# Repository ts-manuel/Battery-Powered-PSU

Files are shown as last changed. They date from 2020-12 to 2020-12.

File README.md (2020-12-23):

# Battery Powered PSU
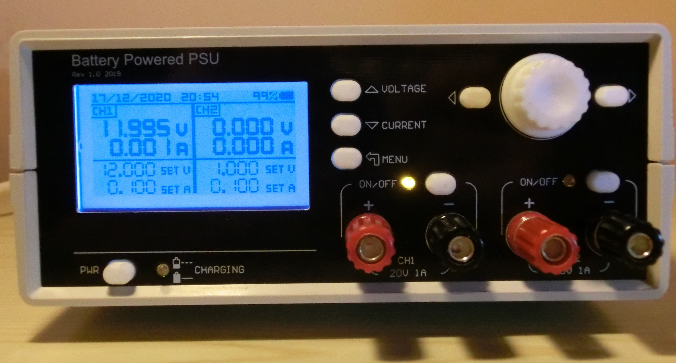
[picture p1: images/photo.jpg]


<!-- TABLE OF CONTENTS -->
<details open="open">
  <summary>Table of Contents</summary>
  <ol>
    <li>
      <a href="#about-the-project">About The Project</a>
    </li>
    <li>
      <a href="#getting-started">Getting Started</a>
      <ul>
        <li><a href="#prerequisites">Prerequisites</a></li>
      </ul>
    </li>
    <li>
        <a href="#theory-of-operation">Theory of Operation</a>
        <ul>
            <li><a href="#battery-block-diagram">Battery Block Diagram</a></li>
            <li><a href="#soc-estimation">SOC Estimation</a></li>
            <li><a href="#charging-and-balancing">Charging and Balancing</a></li>
            <li><a href="#psu-block-diagram">PSU Block Diagram</a></li>
            <li><a href="#custom-transformers">Custom Transformers</a></li>
        </ul>
    </li>
    <li><a href="#future-improvements">Future Improvements</a></li>
    <li><a href="#references">References</a></li>
    <li><a href="#disclaimer">Disclaimer</a></li>
  </ol>
</details>

<!-- ABOUT THE PROJECT -->
## About The Project
This is a dual-channel power supply powered by 6 18650 Lithium-Ion cells. If like me you don't have lots of space, having a power supply that you can move and get out of the way without getting tangled in cables is quite useful. Inspiration comes from the [uSupply](https://www.eevblog.com/projects/usupply/) designed by Dave Jones on the EEVblog. The only thing this has in common with the original uSupply is the [LT3080](https://www.analog.com/media/en/technical-documentation/data-sheets/3080fc.pdf) low dropout voltage regulator on the output. The remaining hardware has been completely engineered from scratch.\
Schematics and PCBs are designed with Circuit Maker, [link](https://workspace.circuitmaker.com/Projects/Details/ts-manuel/Battery-Powered-PSU-Final) to the project.
### Specifications:
* Powered from 6 x 18650 Lithium-Ion cells (56Wh)
* 2x 20V 1A Isolated outputs
* 1 mV Voltage resolution
* 1 mA Current resolution

<!-- GETTING STARTED -->
## Getting Started
There are two MPLAB X projects, `software\BatteryController.X`  is for the battery microcontroller and `software\PowerSupply.X` is for the main power supply microcontroller. To compile the code just open them into MPLAB X.
### Prerequisites
* [MPLAB X v5.30](https://www.microchip.com/development-tools/pic-and-dspic-downloads-archive)
* [MPLAB Code Configurator v4.x](https://www.microchip.com/mplab/mplab-code-configurator)

<!-- BLOCK DIAGRAM -->
## Theory of Operation
The project is split into two circuit boards. The one on the left is the battery, the other is the power supply. The battery board holds six Lithium-Ion cells, the protection and charger circuitry, and a microcontroller to keep track of the SOC (State Of Charge). All the components besides the cells are located on the backside. The power supply board on the right has all the circuitry to handle the user interface and to generate the output voltages. The output voltage is regulated in two steps, there's a switching pre-regulator to keep efficiency high followed by a linear one to reduce noise.
The two boards are connected by a 10-way cable that carries power and control signals. When the power supply is on, the battery sends its SOC to the PSU via UART.
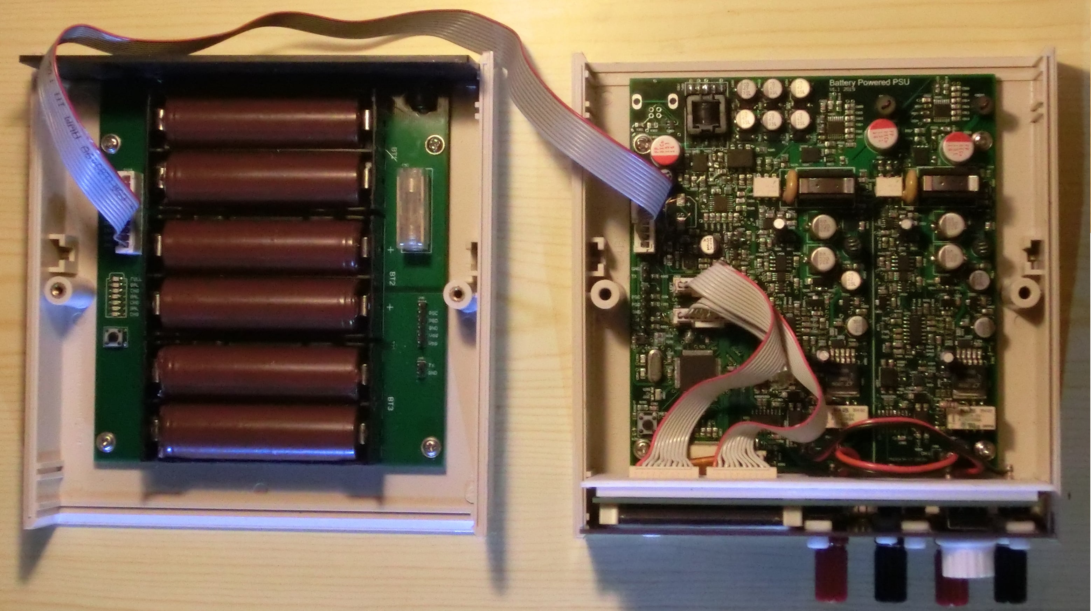
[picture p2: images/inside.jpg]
Inside


### Battery Block Diagram
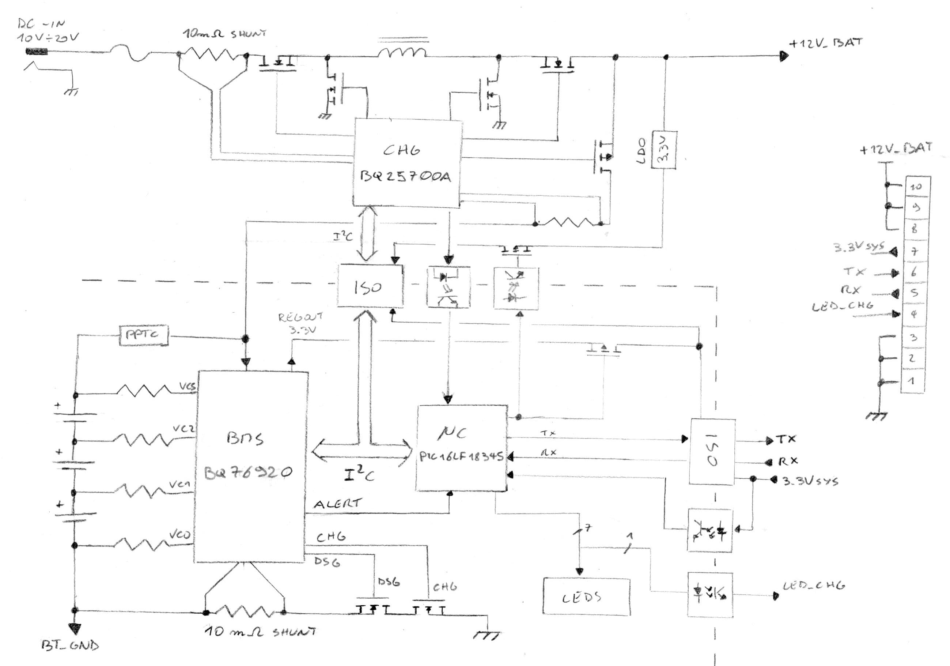
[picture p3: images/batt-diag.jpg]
Battery Block Diagram
\
This is the simplified block diagram for the battery board. This board is responsible for charging and protecting the Lithium-Ion cells. The three main components are the BMS IC, the charging IC, and the microcontroller.\
The BMS [BQ76920](https://www.ti.com/lit/ds/symlink/bq76940.pdf?ts=1608322350104&ref_url=https%253A%252F%252Fwww.google.com%252F) from Texas Instruments, continuously monitors cell voltages and current. If an over-voltage, under-voltage, or over-current condition is detected the cells are immediately disconnected. The IC also features internal balancing FETs that are activated by the microcontroller to balance the cells. The BMS is connected to the microcontroller through I2C.\
The Charger IC [BQ25700A](https://www.ti.com/lit/ds/symlink/bq25700a.pdf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) also from Texas Instruments uses a switching buck-boost converter to take the input voltage and charge the cells with a constant-current constant-voltage scheme. Its I2C interface is connected to the microcontroller through an I2C isolator.\
The microcontroller is a [PIC16LF18345](http://ww1.microchip.com/downloads/en/devicedoc/40001795e.pdf) from Microchip. It keeps track of the battery SOC, balances the cels, and enables/disables the charger. The microcontroller is connected directly to the batteries, when the BMS goes into protection mode and the cells are disconnected from the rest of the circuit, the only things powered are the BMS and the microcontroller.\
To save power, voltage to the I2C isolators is removed when they're not in use.

### SOC Estimation
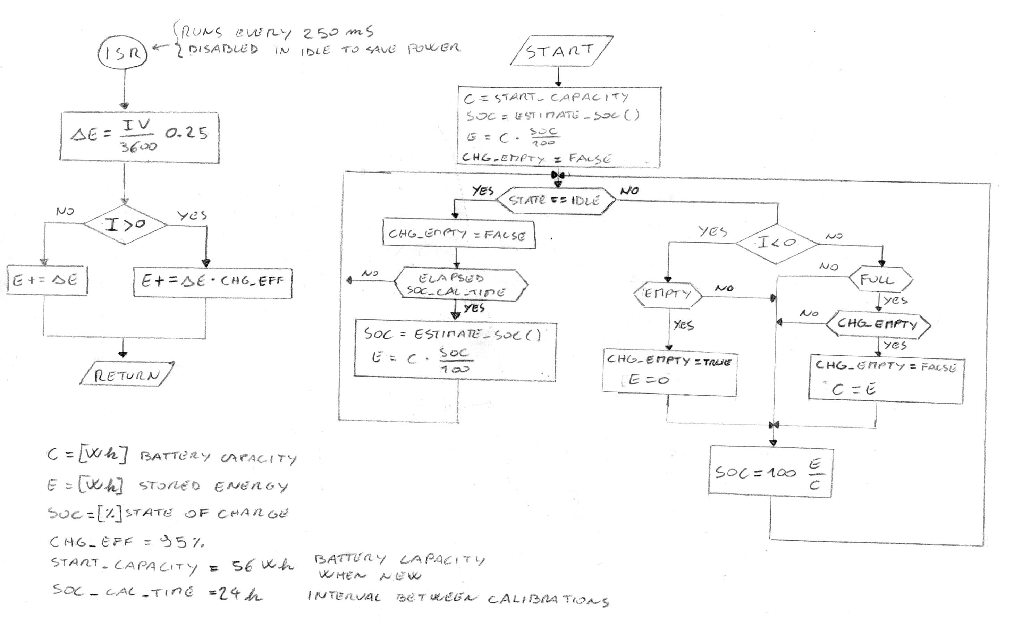
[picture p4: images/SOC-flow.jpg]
SOC Estimation Flow Chart
\
The flow chart above describes the SOC Estimation algorithm adopted, it is a variation of this [Coulomb-Counting Algorithm](https://arxiv.org/ftp/arxiv/papers/1803/1803.10654.pdf). Coulomb-Counting consists of temporal integration of the battery current during charge and discharge. To take into account the battery self-discharge, the SOC is recalibrated by looking at the open-circuit voltage after the battery is left sitting unused for 24 hours. During charge and discharge the coulomb-counter 16-bit ADC inside the BMS is active and configured to trigger an interrupt every 250 ms. Inside the microcontroller, there are three variables: capacity, energy, and SOC. When the board is first powered the capacity is initialized with the expected capacity from a new set of cells, the SOC is estimated from the open-circuit voltage, and energy is set as a fraction of the initial capacity based upon the SOC. Each time the BMS triggers an interrupt the energy is updated, when the battery is empty the energy is set to zero.
At the end of the charging process, if the battery has been charged from empty without interruptions, the accumulated energy is by definition the real battery capacity so the capacity variable is updated. This takes into account the aging of the cells in the SOC estimations.

### Charging and Balancing
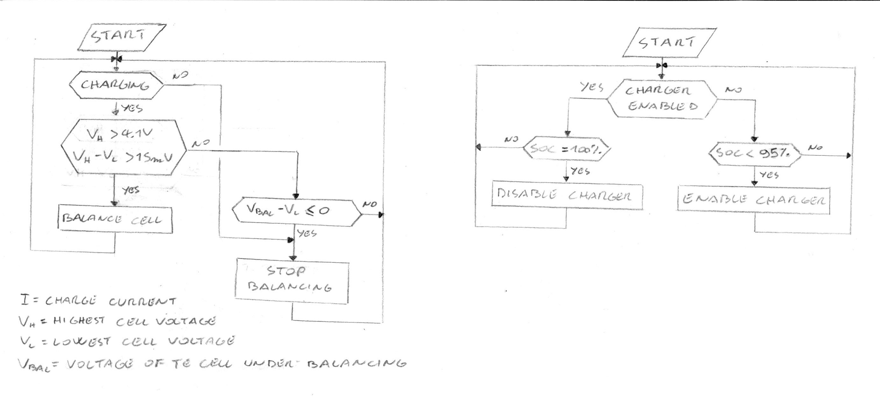
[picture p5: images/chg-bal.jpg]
Charging-Balancing Flowchart
\
The microcontroller controls the charger IC, when the charging cable is plugged in, the charger is enabled if the SOC is less than 95% and it's disabled when SOC reaches 100%.\
Balancing is performed only near the end of charge when the cell voltages are closer. If the difference in voltage between cells is greater than 15 mV, the balancing FET for the cell with the highest voltage is activated. It remains active until its voltage equals that of another cell. This simple scheme works surprisingly well. Once the cells are balanced they remain aligned pretty much on their own and only small corrections are needed.

### PSU Block Diagram
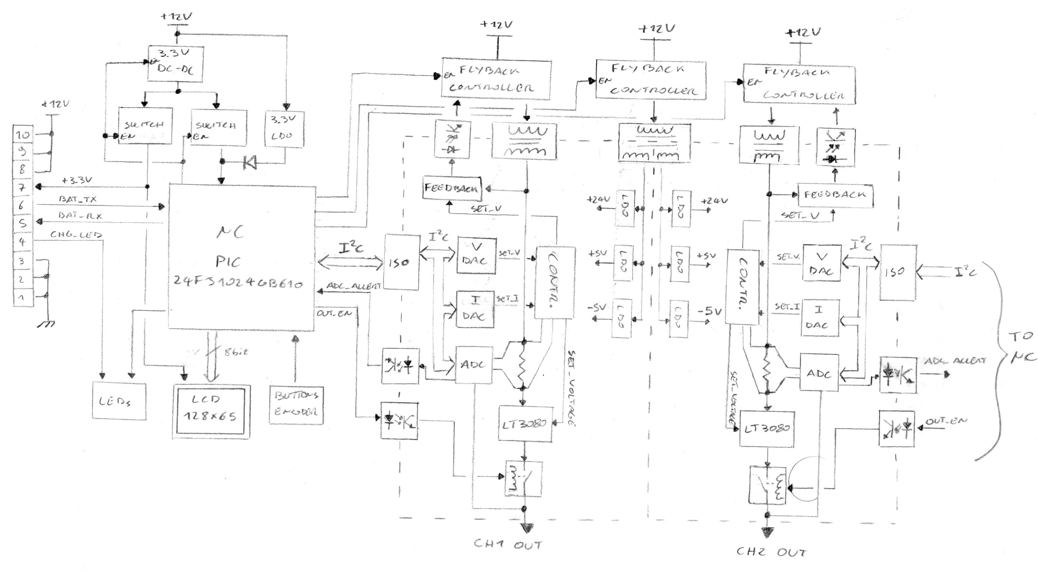
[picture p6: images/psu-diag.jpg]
PSU Block Diagram
\
This is the block diagram for the power supply. The microcontroller [PIC24FJ1024GB610](https://www.microchip.com/wwwproducts/en/PIC24FJ1024GB610) handles the user interface and controls the rest of the circuitry. The connection to the LCD uses the EPMP peripheral configured as an 8-bit 6800 bus. The buttons and the encoder are handled by interrupts. When the power supply is turned off, all the flyback converters are disabled, the 3.3V rail is disabled, and the microcontroller enters sleep mode. During sleep the main 8MHz external clock is halted, the only way to wake the CPU is the interrupt triggered by the power button.\
The power supply has two identical isolated channels, to set the output voltage and current limits, each channel has two DACs connected to the same I2C bus through isolators. Control signals are passed on with optocouplers. The output voltage is regulated in two steps, there is a flyback switching converter to keep isolation between channels followed by a linear regulator to reduce noise. The 100KHz clocks for the flyback converters are provided by the microcontroller, the clock signals for the two converters are 180° out of phase, this prevents the primary side MOSFETs from turning on at the same time thus reducing the RMS load on the primary capacitors. There is also a third flyback converter to provide power to the control circuitry.

### Custom Transformers
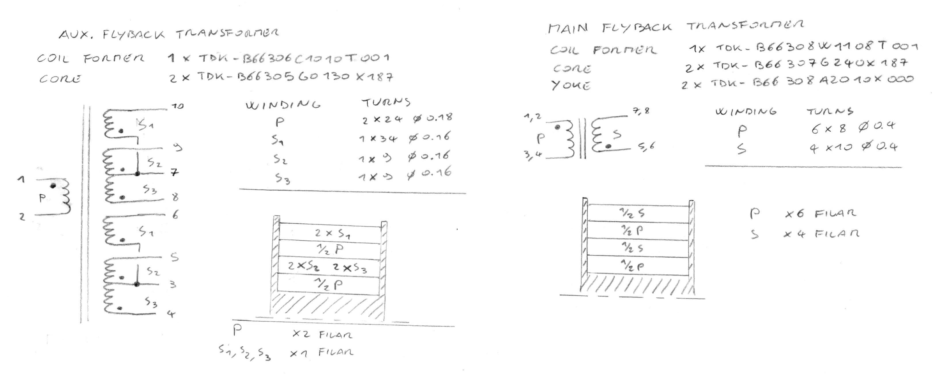
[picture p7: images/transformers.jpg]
Transforrmers
\
There are three custom transformers: two identical ones for the two main flyback converters and one for the auxiliary flyback converter. The picture above shows the winding scheme for each transformer.

<!-- FUTURE IMPROVEMENTS -->
## Future Improvements
* Fix issues with PCBs
* BOM consolidation
* Add USB functionality to the main uC

<!-- REFERENCES -->
## References
* [Implementation of an Improved Coulomb-Counting Algorithm](https://arxiv.org/ftp/arxiv/papers/1803/1803.10654.pdf)
* [A Closer Look at State of Charge and State of Health Estimation Techniques](https://www.analog.com/media/en/technical-documentation/technical-articles/a-closer-look-at-state-of-charge-and-state-health-estimation-techniques.pdf)
* [Lithium-Ion Battery Cell-Balancing Algorithm for Battery Management System Based on Real-Time Outlier Detection](http://downloads.hindawi.com/journals/mpe/2015/168529.pdf)
* [Flyback transformer design considerations for efficiency and EMI](https://www.ti.com/seclit/ml/slup338/slup338.pdf)
* [Flyback Converter Snubber Design](http://www.ridleyengineering.com/images/phocadownload/12_%20flyback_snubber_design.pdf)
* [Battery university - Charging Lithium-ion](https://batteryuniversity.com/learn/article/charging_lithium_ion_batteries)
* [Battery Cell Balancing - What to Balance and How](https://www.ti.com/download/trng/docs/seminar/Topic%202%20-%20Battery%20Cell%20Balancing%20-%20What%20to%20Balance%20and%20How.pdf)
* [Fast Cell Balancing Using External MOSFET](https://www.ti.com/lit/an/slua420a/slua420a.pdf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)
* [Cell balancing buys extra run time and battery life](https://e2echina.ti.com/cfs-file/__key/telligent-evolution-components-attachments/13-112-00-00-00-00-58-11/Cell-balancing-buys-extra-run-time-and-battery-life.pdf)

<!-- DISCLAIMER -->
## Disclaimer
The following project is shared "as is", with the sole objective of being useful. The creator of the described piece of hardware and its associated software cannot guarantee its correct functioning under any circumstance. The author of this project will not be held responsible for any material, personal or economic losses to you or any third parties that may arise from using this design. This project will not be used under any circumstances on systems whose responsibility is critical, or from which people's lives depend upon, directly or indirectly.

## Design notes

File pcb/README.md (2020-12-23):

## Issues with the PCBs
The current PCBs have a couple of issues, to get them working perform the following steps.

### Battery
* Add 10K pull-up resistor to the uC reset pin
* Add 470K pull-up resistor to U50 pin 4
* Cut trace from U101 pin 1 to U100 pin 10 and jumper from U101 pin 1 to U100 pin 1
* Cut trace from connector J101 pin 7, install a series 15 Ohm resistor with a 5V zener diode to GND

### Front Panel Graphics
* No issues

### Front Panel
* No issues

### Power Supply
* Cut trace from resistor R207 and uC
* Cut trace from resistor R208 and uC
* Add jumper from uC pin 43 to R207
* Add jumper across D201
* swap I2C lines for U402 and U404
* Cut trace from U404 pin 1 and connect pull-up resistor to 5V
* Cut trace from U407 pin 2, leave pin 2 floating
* Remove C451, C452 and replace them with a 22uF electrolytic
* Remove C551, C552 and replace them with a 22uF electrolytic
* Put a 4.7uF electrolytic in parallel with R623
* Put a 4.7uF electrolytic in parallel with R523
* Change R520, R620, R670 to 22K

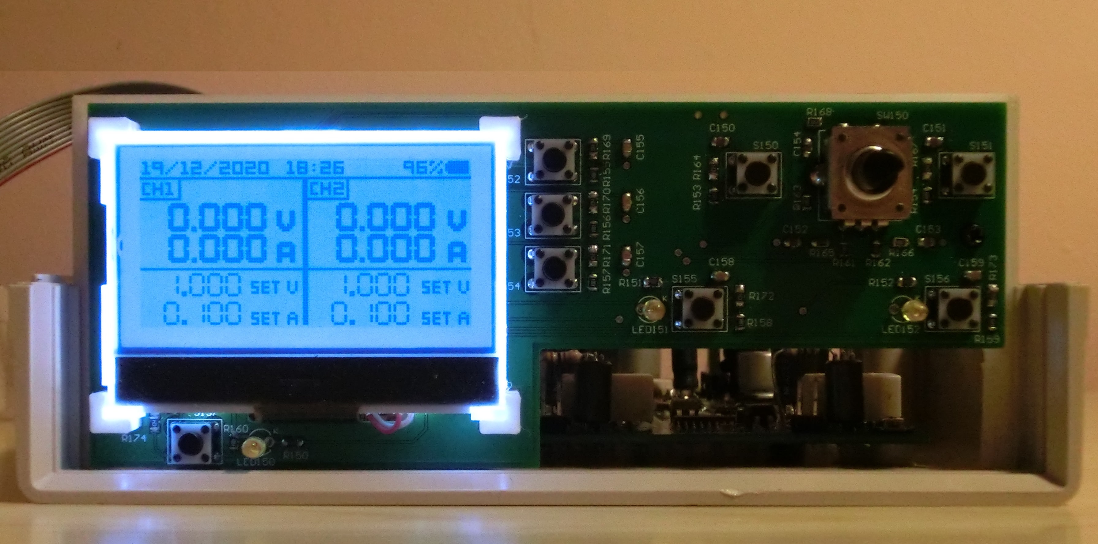
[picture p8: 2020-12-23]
images/front.jpg

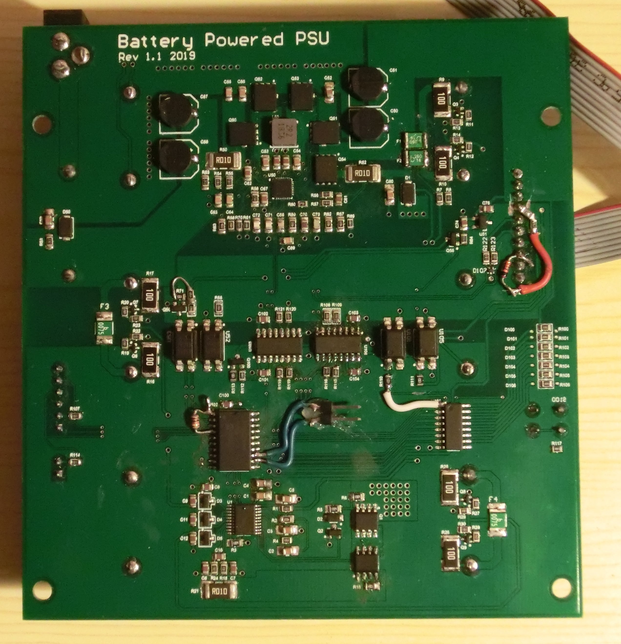
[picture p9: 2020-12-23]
images/battery.jpg

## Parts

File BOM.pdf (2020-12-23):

Quantity | Part Number | Description | Designator | Value
1 | 63074-510-039 CM6-225 Bone Kit (https://www.mouser.it/ProductDetail/PacTec/63074-510-039-CM6-225-Bone-Kit/?qs=e%252B5Je2AHyOjkqM0dwzHt2g%3D%3D) | Enclosures, Boxes & Cases KIT 6.08X6.25X2.5
1 | 3365/10-CUT-LENGTH (https://www.mouser.it/ProductDetail/3M-Electronic-Solutions-Division/3365-10-CUT-LENGTH/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) | Flat Cables .050 10 COND. 28AWG ROUND 1PC=1FT
3 | BK-18650-PC4 | Batt Holder 18650 2 Cell Pc Pin | BT1, BT2, BT3
1 | NHD-C12865AR-FSW-GBW (https://www.mouser.it/ProductDetail/Newhaven-Display/NHD-C12865AR-FSW-GBW/?qs=g3KGrJtCh1xpa8RpWyJ02g%3D%3D) | LCD Graphic Display Modules & Accessories STN-GRAY 59.0 x 42.0 x 5.9 | | 128x65
2 | TX2SA-5V (https://www.mouser.it/ProductDetail/Panasonic-Industrial-Devices/TX2SA-5V/?qs=HLLy2pIPwusM7KldQLtGKQ%3D%3D) | Low Signal Relays - PCB 2A 5VDC DPDT NON-LATCHING SMD | K450, K550
10 | FSM4JH (https://www.mouser.it/ProductDetail/TE-Connectivity-Alcoswitch/FSM4JH/?qs=g%252BEszo6zu8OwVWrHD2r3Rw%3D%3D) | Tactile Switches SPST OFF-(ON) Round pushbutton | S100, S150, S151, S152, S153, S154, S155, S156, S157, S250
1 | EN12-HS22AF20 (https://www.mouser.it/ProductDetail/BI-Technologies-TT-Electronics/EN12-HS22AF20/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) | Encoders 12mm | SW150
1 | LFXTAL003156Bulk (https://www.mouser.it/ProductDetail/IQD/LFXTAL003156Bulk/?qs=e4%2FAndAAwgJ2Z9T5UFLWLw%3D%3D) | Crystals 8.0MHz 11.05 x 4.7 x 4.1mm | X251 | 8 MHz
1 | LFXTAL009709Bulk (https://www.mouser.it/ProductDetail/IQD/LFXTAL009709Bulk/?qs=GJ%2F2ZGcr5uMZJX4giCbLEA%3D%3D) | Crystals 32.7680kHz 3.2 x 1.5 x 0.9mm | X250 | 32,768 KHz
5 | EMZS350ARA331MHA0G (https://www.mouser.it/ProductDetail/United-Chemi-Con/EMZS350ARA331MHA0G/?qs=y6ZabgHbY%252Bwd%2FyVNgmLAUg%3D%3D) | Aluminium Electrolytic Capacitors - SMD 330uF 35V 20% AEC-Q200 | C210, C504, C505, C604, C605 | 330 uF
3 | RR71C151MDN1 (https://www.mouser.it/ProductDetail/Nichicon/RR71C151MDN1/?qs=bW1g5Sys4u1OTM2uqSq9sg%3D%3D) | Aluminium Organic Polymer Capacitors 16V 150uF 7Mohms | C503, C603, C652 | 150 uF
12 | UWX1V470MCL1GB (https://www.mouser.it/ProductDetail/Nichicon/UWX1V470MCL1GB/?qs=6avfeC6zeS4P0xwjmzwy4Q%3D%3D) | Aluminium Electrolytic Capacitors - SMD 35volts 47uF AEC-Q200 | C201, C451, C454, C506, C554, C606, C650, C656, C660, C666, C670, C674 | 47 uF
4 | APMA250ARA220MF30S (https://www.mouser.it/ProductDetail/United-Chemi-Con/APMA250ARA220MF30S/?qs=r5DSvlrkXmIcGG94gOJQuA%3D%3D) | Aluminium Organic Polymer Capacitors 22uF 20% 25V Super Low ESR | C50, C51, C57, C58 | 22 uF
15 | GRM21BR61E106MA73L (https://www.mouser.it/ProductDetail/Murata-Electronics/GRM21BR61E106MA73L/?qs=2W5sgKM%2F371odLMyCilkag%3D%3D) | Multilayer Ceramic Capacitors MLCC - SMD/SMT 0805 10uF 25volts X5R 20% | C1, C2, C3, C4, C5, C59, C52, C60, C205, C206, C255, C658, C662, C672, C676 | 10 uF
38 | CC0805ZRY5V8BB105 (https://www.mouser.it/ProductDetail/Yageo/CC0805ZRY5V8BB105/?qs=BKNoF%2F0xMNtOYuUY4MbPwQ%3D%3D) | Multilayer Ceramic Capacitors MLCC - SMD/SMT 1.0uF 25V Y5V-20/+80% | C62, C65, C66, C67, C74, C75, C203, C207, C208, C209, C300, C302, C303, C304, C305, C400, C408, C462, C501, C508, C510, C512, C514, C524, C551, C552, C562, C601, C608, C609, C611, C613, C624, C653, C678, C680, C682, C687 | 1 uF
90 | CC0805ZRY5V9BB104 (https://www.mouser.it/ProductDetail/Yageo/CC0805ZRY5V9BB104/?qs=AgBp2OyFlx8gs88HUkKifA%3D%3D) | Multilayer Ceramic Capacitors MLCC - SMD/SMT 100nF 50V Y5V-20/+80% | C6, C7, C8, C9, C10, C11, C12, C61, C100, C101, C102, C103, C104, C150, C151, C152, C153, C154, C155, C156, C157, C158, C159, C160, C200, C202, C204, C252, C256, C257, C258, C259, C260, C261, C301, C307, C308, C309, C310, C311, C314, C350, C351, C352, C353, C401, C402, C403, C404, C405, C407, C409, C410, C411, C412, C450, C455, C456, C457, C460, C461, C463, C511, C513, C515, C516, C517, C519, C550, C555, C556, C557, C560, C561, C563, C610, C612, C614, C615, C616, C619, C651, C657, C661, C667, C671, C675, C679, C681, C683 | 100 nF
4 | C0805C473M5UACTU (https://www.mouser.it/ProductDetail/KEMET/C0805C473M5UACTU/?qs=kLwEmPtpBV%2Flr0trn5FFPw%3D%3D) | Multilayer Ceramic Capacitors MLCC - SMD/SMT 50V 0.047uF Z5U 0805 20% | C53, C54, C453, C553 | 47 nF
25 | C0805C153K5RACTU (https://www.mouser.it/ProductDetail/KEMET/C0805C153K5RACTU/?qs=SmE4D0qXCUQDzSI7kMUD0w%3D%3D) | Multilayer Ceramic Capacitors MLCC - SMD/SMT 50V 0.015uF X7R 0805 10% | C56, C306, C312, C313, C406, C413, C459, C500, C502, C509, C521, C559, C600, C602, C617, C621, C654, C659, C663, C664, C665, C668, C669, C673, C684 | 15 nF
2 | VY2472M49Y5US6TV7 (https://www.mouser.it/ProductDetail/Vishay-BC-Components/VY2472M49Y5US6TV7/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) | Safety Capacitors 4700pF Y440 300vac 20% Y5U | C518, C618 | 4,7 nF
12 | 885012207087 (https://www.mouser.it/ProductDetail/Wurth-Elektronik/885012207087/?qs=0KOYDY2FL29zqUuVSiTMTA%3D%3D) | Multilayer Ceramic Capacitors MLCC - SMD/SMT WCAP-CSGP 1500pF 0805 10% 50V MLCC | C55, C63, C64, C69, C458, C507, C522, C558, C607, C622, C655, C685 | 1,5 nF
1 | 885012207085 (https://www.mouser.it/ProductDetail/Wurth-Elektronik/885012207085/?qs=0KOYDY2FL2%252BDz04pPbTZyQ%3D%3D) | Multilayer Ceramic Capacitors MLCC - SMD/SMT WCAP-CSGP 680pF 0805 10% 50V MLCC | C73 | 680 pF
5 | 885012007057 (https://www.mouser.it/ProductDetail/Wurth-Elektronik/885012007057/?qs=0KOYDY2FL29zTzQpzMWdyA%3D%3D) | Multilayer Ceramic Capacitors MLCC - SMD/SMT WCAP-CSGP 100pF 0805 5% 50V MLCC | C71, C72, C523, C623, C677 | 100 pF
4 | 885012007054 (https://www.mouser.it/ProductDetail/Wurth-Elektronik/885012007054/?qs=0KOYDY2FL29NRNiRMAYbKg%3D%3D) | Multilayer Ceramic Capacitors MLCC - SMD/SMT WCAP-CSGP 33pF 0805 5% 50V MLCC | C68, C520, C620, C686 | 33 pF
3 | 885012007052 (https://www.mouser.it/ProductDetail/Wurth-Elektronik/885012007052/?qs=0KOYDY2FL28Fngqb5geh6g%3D%3D) | Multilayer Ceramic Capacitors MLCC - SMD/SMT WCAP-CSGP 15pF 0805 5% 50V MLCC | C70, C253, C254 | 15 pF
2 | 885012006092 (https://www.mouser.it/ProductDetail/Wurth-Elektronik/885012006092/?qs=MLItCLRbWsxQak2tJVd%252Brg%3D%3D) | Multilayer Ceramic Capacitors MLCC - SMD/SMT WCAP-CSGP 100V 4.7pF 0603 .25pFTol | C250, C251 | 5,6 pF
4 | RC0805FR-101ML (https://www.mouser.it/ProductDetail/Yageo/RC0805FR-101ML/?qs=g6xwsc4j%252B%2FquvT%252BzGahIFg%3D%3D) | Thick Film Resistors - SMD 1M OHM 1% | R3, R5, R6, R15 | 1 MΩ
9 | CR0805-FX-4703ELF (https://www.mouser.it/ProductDetail/Bourns/CR0805-FX-4703ELF/?qs=TYKCbaKwe1DeM4TzIfy34g%3D%3D) | Thick Film Resistors - SMD 470K 1% | R72, R513, R514, R515, R613, R614, R615, R666, R671 | 470 KΩ
8 | ERJ-6ENF1333V (https://www.mouser.it/ProductDetail/Panasonic/ERJ-6ENF1333V/?qs=JjxTDIFmKPQez5BAYro2WA%3D%3D) | Thick Film Resistors - SMD 0805 133Kohms 1% AEC-Q200 | R61, R64, R69, R70, R112, R117, R510, R610 | 133 KΩ
24 | CR0805-FX-1003ELF (https://www.mouser.it/ProductDetail/Bourns/CR0805-FX-1003ELF/?qs=tknLyCMIRbPd3RvyRhvkuQ%3D%3D) | Thick Film Resistors - SMD 100K 1% | R164, R167, R169, R170, R171, R172, R173, R174, R203, R302, R469, R508, R518, R520, R524, R569, R608, R618, R620, R624, R655, R669, R670, R673 | 100 KΩ
17 | CR0805-FX-4022ELF (https://www.mouser.it/ProductDetail/Bourns/CR0805-FX-4022ELF/?qs=TYKCbaKwe1CyApdNi%252BhM5Q%3D%3D) | Thick Film Resistors - SMD 40.2K 1% | R2, R59, R62, R63, R67, R202, R204, R454, R459, R461, R467, R511, R554, R559, R561, R567, R611 | 40,2 KΩ
54 | CR0805-FX-1002ELF (https://www.mouser.it/ProductDetail/Bourns/CR0805-FX-1002ELF/?qs=tknLyCMIRbPr%252BDD0s0nG9g%3D%3D) | Thick Film Resistors - SMD 10K 1% | R4, R11, R12, R19, R20, R27, R28, R60, R68, R115, R116, R118, R119, R120, R121, R124, R165, R166, R168, R200, R250, R350, R351, R352, R353, R456, R457, R460, R462, R463, R503, R504, R506, R517, R521, R522, R523, R556, R557, R560, R562, R563, R603, R604, R606, R617, R621, R622, R623, R652, R664, R668, R672 | 10 KΩ
18 | CR0805-FX-2201ELF (https://www.mouser.it/ProductDetail/Bourns/CR0805-FX-2201ELF/?qs=Woncl1%2FcWdhqe6ZSJY8Gqw%3D%3D) | Thick Film Resistors - SMD 2.2K 1% | R65, R66, R100, R101, R102, R103, R104, R105, R106, R108, R109, R205, R206, R257, R258, R519, R619, R665 | 2,2 KΩ
48 | CR0805-FX-1001ELF (https://www.mouser.it/ProductDetail/Bourns/CR0805-FX-1001ELF/?qs=tknLyCMIRbOJasvgRv5Bdg%3D%3D) | Thick Film Resistors - SMD 1K 1% | R71, R110, R111, R113, R153, R154, R155, R156, R157, R158, R159, R160, R161, R162, R163, R300, R354, R355, R356, R357, R401, R403, R404, R405, R407, R409, R452, R453, R455, R458, R464, R465, R466, R468, R471, R516, R552, R553, R555, R558, R564, R565, R566, R568, R571, R616, R674, R675 | 1 KΩ
60 | CR0805-JW-101ELF (https://www.mouser.it/ProductDetail/Bourns/CR0805-JW-101ELF/?qs=wL7NMIHXUPl5EcPQbx1sug%3D%3D) | Thick Film Resistors - SMD 100ohm 5% | R1, R7, R8, R13, R14, R18, R22, R23, R24, R29, R30, R54, R55, R56, R57, R107, R114, R122, R123, R150, R151, R152, R207, R208, R251, R253, R254, R255, R256, R301, R303, R304, R305, R400, R472, R406, R470, R500, R501, R502, R509, R525, R570, R572, R600, R601, R602, R609, R625, R650, R651, R653, R656, R657, R659, R660, R661, R662, R663, R667 | 100 Ω
11 | CR0805-JW-150ELF (https://www.mouser.it/ProductDetail/Bourns/CR0805-JW-150ELF/?qs=wL7NMIHXUPk1QYaFX5bKWA%3D%3D) | Thick Film Resistors - SMD 15ohm 5% | R58, R125, R201, R252, R402, R408, R450, R507, R550, R607, R654 | 15 Ω
6 | CRM2512AJW-100ELF (https://www.mouser.it/ProductDetail/Bourns/CRM2512AJW-100ELF/) | Thick Film Resistors - SMD 2512 10 ohms 5% 2W TC200 AEC-Q200 | R9, R10, R16, R17, R25, R26 | 10 Ω
4 | CR0805-J/-1R0ELF (https://www.mouser.it/ProductDetail/Bourns/CR0805-J-1R0ELF/?qs=wL7NMIHXUPlPHo4IdJ6pLQ%3D%3D) | Thick Film Resistors - SMD 1OHM 1/8WATT 5% | R51, R53, R505, R605 | 1 Ω
1 | ERJ-U6SFR20V (https://www.mouser.it/ProductDetail/Panasonic/ERJ-U6SFR20V/?qs=5aG0NVq1C4x5InvksrvATQ%3D%3D) | Thick Film Resistors - SMD 0805 0.25W 1% .20ohms AEC-Q200 | R658 | 200 mΩ
2 | KRL1220E-C-R100-F-T1 (https://www.mouser.it/ProductDetail/Susumu/KRL1220E-C-R100-F-T1/?qs=u4fy%2FsgLU9M3gjysAY1wng%3D%3D) | Current Sense Resistors - SMD 1/2W 0.100 Ohm 1% 50ppm | R451, R551 | 100 mΩ
2 | LVT12R0200FER (https://www.mouser.it/ProductDetail/Ohmite/LVT12R0200FER/?qs=F5EMLAvA7IDowLDno1C4%2FA%3D%3D) | Current Sense Resistors - SMD 0.02 ohm 1% 1.0W Current Sense | R512, R612 | 20 mΩ
3 | CRA2512-FZ-R010ELF (https://www.mouser.it/ProductDetail/Bourns/CRA2512-FZ-R010ELF/?qs=WqWCsLCZBkoNPiv%2FXVnYvw%3D%3D) | Current Sense Resistors - SMD 0.010ohms 1% +/- 50PPM | R21, R50, R52 | 10 mΩ
2 | V8P8-M3/86A (https://www.mouser.it/ProductDetail/Vishay-General-Semiconductor/V8P8-M3-86A/?qs=ZTNTdOMgtc2UPQ6m5lrVAg%3D%3D) | Schottky Diodes & Rectifiers 8A, 80V,TRENCH SKY RECT. | D500, D600
10 | VSS8D5M15-M3/H (https://www.mouser.it/ProductDetail/Vishay-General-Semiconductor/VSS8D5M15-M3-H/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) | Schottky Diodes & Rectifiers 5A, 150V, SLIMSMAW TRENCH SKY RECT. | D1, D50, D450, D550, D650, D652, D656, D657, D659, D662
9 | BAS16GWX (https://www.mouser.it/ProductDetail/Nexperia/BAS16GWX/?qs=EO%252B2iqeaG01Q6tVOPMDHpw%3D%3D) | Diodes - General Purpose, Power, Switching DIODE-GP POWER SWITCHING | D2, D201, D451, D452, D502, D551, D552, D602, D653
2 | UESD3.3DT5G (https://www.mouser.it/ProductDetail/ON-Semiconductor/UESD33DT5G/?qs=OSf9jACorva97Nbp9gtTcQ%3D%3D) | ESD Suppressors / TVS Diodes ZEN ESD PROTECT | D107, D202
1 | D1213A-04TS-7 (https://www.mouser.it/ProductDetail/Diodes-Incorporated/D1213A-04TS-7/?qs=gfe7vQ8txpV8At9DdXhTqA%3D%3D) | ESD Suppressors / TVS Diodes 4 Ch TVS Diode Array 3.3V 6.0A 300mW | D300
10 | SMAZ30-13-F (https://www.mouser.it/ProductDetail/Diodes-Incorporated/SMAZ30-13-F/?qs=L05Q2YWcgvZELf9C%2Fjq4gw%3D%3D) | Zener Diodes 30V 1W | D400, D401, D501, D601, D651, D654, D655, D658, D660, D661 | 30 V
2 | BZT52C5V1-7-F (https://www.mouser.it/ProductDetail/Diodes-Incorporated/BZT52C5V1-7-F/?qs=FFy5bLXC7EennpZVc1%2Fcow%3D%3D) | Zener Diodes 500mW 5.1V Zener AEC-Q101 Qualified | D108, D200 | 5,1 V
3 | BZX84C8V2LT1G (https://www.mouser.it/ProductDetail/ON-Semiconductor/BZX84C8V2LT1G/?qs=vNc2DXHODiKCF4p1YfaM5g%3D%3D) | Zener Diodes 8.2V 250mW | D3, D4, D5 | 8,2 V
7 | AP2012EC (https://www.mouser.it/ProductDetail/Kingbright/AP2012EC/?qs=VdjlWU%2FzoOFeVwl4qeUhTA%3D%3D) | Standard LEDs - SMD RED WATER CLEAR | D100, D101, D102, D103, D104, D105, D106 | LED RED
3 | 151031YS06000 (https://www.mouser.it/ProductDetail/Wurth-Elektronik/151031YS06000/?qs=LlUlMxKIyB3xSYYW%252BcuBiQ%3D%3D) | Standard LEDs - Through Hole WL-TMRC THT Mono Diffused Rnd 3mm Ylw | LED150, LED151, LED152
2 | NTMS4920NR2G (https://www.mouser.it/ProductDetail/ON-Semiconductor/NTMS4920NR2G/?qs=xs5SEmPsiDaTFXtCLlWTOQ%3D%3D) | MOSFET 30V 136A 4.3 mOhm Single N-Chan SO-8 | Q1, Q5
3 | BSS84PH6433XTMA1 (https://www.mouser.it/ProductDetail/Infineon-Technologies/BSS84PH6433XTMA1/?qs=Dj8dEyEphkMfpXG7rJVAAQ%3D%3D) | MOSFET P-Ch -60V -170mA SOT-23-3 | Q2, Q55, Q100
6 | DMG1012TQ-7 (https://www.mouser.it/ProductDetail/Diodes-Incorporated/DMG1012TQ-7/?qs=CfuTe0Pnivqwal6hv2%252B5LA%3D%3D) | MOSFET N-Ch 20V 630mA Vgs4,5V | Q3, Q4, Q6, Q7, Q8, Q9
7 | NVMFS5C673NLWFAFT1G (https://www.mouser.it/ProductDetail/ON-Semiconductor/NVMFS5C673NLWFAFT1G/?qs=HXFqYaX1Q2ygg0mJcbysOw%3D%3D) | MOSFET TRENCH 6 60V NFET | Q50, Q51, Q52, Q53, Q500, Q600, Q650
1 | SI7149ADP-T1-GE3 (https://www.mouser.it/ProductDetail/Vishay-Semiconductors/SI7149ADP-T1-GE3/?qs=vgn07B5hXauIZBHl%2Fj5hoQ%3D%3D) | MOSFET -30V Vds 25V Vgs PowerPAK SO-8 | Q54
8 | MMBT3904LT1G (https://www.mouser.it/ProductDetail/ON-Semiconductor/MMBT3904LT1G/?qs=HVbQlW5zcXUYZ2Fy0YF3FQ%3D%3D) | Bipolar Transistors - BJT NPN GENERAL PURPOSE | Q56, Q300, Q450, Q451, Q452, Q550, Q551, Q552
2 | MMBT3906LT1G (https://www.mouser.it/ProductDetail/ON-Semiconductor/MMBT3906LT1G/?qs=HVbQlW5zcXXO9RcjXx8aQw%3D%3D) | Bipolar Transistors - BJT 200mA 40V PNP | Q501, Q601
2 | 0ZCG0260BF2B (https://www.mouser.it/ProductDetail/Bel-Fuse/0ZCG0260BF2B/?qs=SRYZG9HaIQ2cF%2Fn2v7uG%2FQ%3D%3D) | Resettable Fuses - PPTC | F1, F2 | 2,6 A
2 | 0ZCG0075FF2C (https://www.mouser.it/ProductDetail/Bel-Fuse/0ZCG0075FF2C/?qs=SRYZG9HaIQ2tFErOmYU4pA%3D%3D) | Resettable Fuses - PPTC | F3, F4 | 1,5 A
1 | 64600001223 (https://www.mouser.it/ProductDetail/Littelfuse/64600001223/?qs=up76HT6PtJjfTS5uVso6wg%3D%3D) | Fuse Holder ACS 5X20MM BLOCK 3.2MM PINS | F50
7 | 2944666631 (https://www.mouser.it/ProductDetail/Fair-Rite/2944666631/?qs=aTFcLA2DbqsXEIoqj7tOHQ%3D%3D) | Ferrite Beads 44 WOUND BEAD Z=690 OHM @100MHz | FB450, FB500, FB501, FB550, FB600, FB601, FB650
7 | 2512061027Y0 (https://www.mouser.it/ProductDetail/Fair-Rite/2512061027Y0/?qs=paL1wOLBYNc4lLfIVw3VjA%3D%3D) | Ferrite Beads MULTILAYER CHIP BEAD Z=1K OHM @100MHz 25% | FB100, FB651, FB652, FB653, FB654, FB655, FB656
1 | SRP5030CA-2R2M (https://www.mouser.it/ProductDetail/Bourns/SRP5030CA-2R2M/?qs=MLItCLRbWsy6rFgTniE8hg%3D%3D) | Fixed Inductors 2.2uH20% 9.7A | L50 | 2,2 uH
1 | NRS4018T3R3MDGJ (https://www.mouser.it/ProductDetail/Taiyo-Yuden/NRS4018T3R3MDGJ/?qs=PzICbMaShUcpCsTbMe7d4g%3D%3D) | Fixed Inductors 4018 3.3uH 66mOhms +/-20%Tol 2000mA | L200 | 3,3 uH
2 | B66308W1108T001 (https://www.mouser.it/ProductDetail/EPCOS-TDK/B66308W1108T001/?qs=yq14W93GGCG7A9Yq8B%252B7Mg%3D%3D) | Ferrite Cores & Accessories FERRITE CORES & ACCS CF-E16/8/5-V-1S-8P | T500, T600
4 | B66308A2010X000 (https://www.mouser.it/ProductDetail/EPCOS-TDK/B66308A2010X000/?qs=%2FsLciWRBLmCCSb7EPMxU8A%3D%3D) | Ferrite Cores & Accessories CLM-E16 2 PCS REQUIRED | T500, T600
4 | B66307G0240X187 (https://www.mouser.it/ProductDetail/EPCOS-TDK/B66307G0240X187/?qs=%2FsLciWRBLmCBrMOsFxKwjw%3D%3D) | Ferrite Cores & Accessories E16/8/5 N87 GAP 0,24+-0,02MM | T500, T600
1 | B66306C1010T001 (https://www.mouser.it/ProductDetail/EPCOS-TDK/B66306C1010T001/?qs=%2FsLciWRBLmCYTK9h1swblA%3D%3D) | Ferrite Cores & Accessories CF-E13/7 4-HSG-1S-10P | T650
2 | B66305G0130X187 (https://www.mouser.it/ProductDetail/EPCOS-TDK/B66305G0130X187/?qs=%2FsLciWRBLmA%252Bobhbyr7vMA%3D%3D) | Ferrite Cores & Accessories CORE 112uH 0.7A | T650
1 | CON-SOCJ-2155 (https://www.mouser.it/ProductDetail/Gravitech/CON-SOCJ-2155/?qs=fkzBJ5HM%252BdCcpvFQyQZHtA%3D%3D) | DC Power Connectors Power Jack/Connector 2.1mm x 5.5mm | J50
1 | M20-9992046 (https://www.mouser.it/ProductDetail/Harwin/M20-9992046/?qs=%252Bk6%2F5FB6qrkVgm0dNoxueg%3D%3D) | Headers & Wire Housings 20 SIL VERTICAL PIN HEADER TIN | J100, J102, J250, J305, J450, J550 | 20 pin
1 | 1775470-2 (https://www.mouser.it/ProductDetail/TE-Connectivity/1775470-2/?qs=fvVej%2FMj3jfnR3bxW9CKNA%3D%3D) | Headers & Wire Housings 2 POS HDR VERT SMT 2.0mm | J301 | 2 pin
1 | 292304-1 (https://www.mouser.it/ProductDetail/TE-Connectivity/292304-1/?qs=G%2F5vCLrg9vwiXeMJMHNpsA%3D%3D) | USB Connectors 4P 'B' RECEPTACLE | J302
1 | 54104-3031 (https://www.mouser.it/ProductDetail/Molex/54104-3031/?qs=OdNwOVlk5%2Fgp%252BOXEChIRCA%3D%3D) | FFC & FPC Connectors 0.5 FPC ZIF SMT R/AU prCont30CktEmbsTpPkg | J300
2 | 53375-1010 (https://www.mouser.it/ProductDetail/Molex/53375-1010/?qs=sGAEpiMZZMvlX3nhDDO4AIQZDn9AnPIhjUSyRy4biR0%3D) | Headers & Wire Housings 2.5 WTB WAFER ASSY W/KINK 10CKT | J101, J200
2 | 51103-1000 (https://www.mouser.it/ProductDetail/Molex/51103-1000/) | Headers & Wire Housings 2.5 W/B REC HSG 10P POS LOCK | J101, J200
20 | 50351-8000 (Cut Strip) (https://www.mouser.it/ProductDetail/Molex/50351-8000-Cut-Strip/?qs=LVm7ROZMjqMJwdrhPNcVpA%3D%3D) | Headers & Wire Housings MN-LK TERM 22-28G F Cut Strip of 100 | J101, J200
4 | 35362-1050 (https://www.mouser.it/ProductDetail/Molex/35362-1050/?qs=zSw%2FV05vmENRjUt0KxyY4w%3D%3D) | Headers & Wire Housings 10 Ckt Vert. Hdr. Sherlock W-T-B | J150, J151, J303, J304
4 | 35507-1000 (https://www.mouser.it/ProductDetail/Molex/35507-1000/?qs=qn91RcX915i7nrkkjTKU0g%3D%3D) | Headers & Wire Housings 10 Ckt Housing Sherlock W-T-B | J150, J151, J303, J304
40 | 50212-8000 (Cut Strip) (https://www.mouser.it/ProductDetail/Molex/50212-8000-Cut-Strip/?qs=LVm7ROZMjqNrWakD077n9Q%3D%3D) | Headers & Wire Housings CRMP TERM 24-30G F Cut Strip of 100 | J150, J151, J303, J304
1 | BQ7692006PWR (https://www.mouser.it/ProductDetail/Texas-Instruments/BQ7692006PWR/?qs=%2Fd%252BFzHvH4c1cik2Itzn1yQ%3D%3D) | Battery Management Li-Ion, Li-Phosphate Battery Moniter | U1
1 | BQ25700ARSNR (https://www.mouser.it/ProductDetail/Texas-Instruments/BQ25700ARSNR/?qs=5aG0NVq1C4y0uoyVOLJvjA%3D%3D) | Battery Management SMBus Battery Buck-Boost Charge Controller 32-QFN | U50
2 | MCP1703T-3302E/CB (https://www.mouser.it/ProductDetail/Microchip-Technology/MCP1703T-3302E-CB/?qs=gsqZ4L1luKqP0F3TlxYEUw%3D%3D) | LDO Voltage Regulators Low Iq 250mA LDO Vin 16V maxVout 3.3V | U51, U203
1 | TPS561201DDCR (https://www.mouser.it/ProductDetail/Texas-Instruments/TPS561201DDCR/?qs=5aG0NVq1C4ySUOSRQSt9MQ%3D%3D) | Switching Voltage Regulator 4.5V to 17V Input, 1A Synchronous Step-Down | U200
2 | L78L24ACUTR (https://www.mouser.it/ProductDetail/STMicroelectronics/L78L24ACUTR/?qs=xMqGwzzuGkIForVItIhWPQ%3D%3D) | Linear Voltage Regulators 24V 0.1A Positive | U650, U653 | 24 V
2 | L78L05ABUTR (https://www.mouser.it/ProductDetail/STMicroelectronics/L78L05ABUTR/?qs=1feNxqzJ94QQZYRl%252B78DYA%3D%3D) | Linear Voltage Regulators 5.0V 0.1A Positive | U651, U654 | 5 V
2 | L79L05ABUTR (https://www.mouser.it/ProductDetail/STMicroelectronics/L79L05ABUTR/?qs=XYwxl0q5LLRDje%252BMXBdxPA%3D%3D) | Linear Voltage Regulators 5.0V 0.1A Negative | U652, U655 | -V5
1 | TL431ACDBZR (https://www.mouser.it/ProductDetail/Texas-Instruments/TL431ACDBZR/?qs=odmYgEirbwzMcBuFx%2Fo8hQ%3D%3D) | Voltage References Adjustable Precision Shunt Regulator | U658
8 | LTV-816S (https://www.mouser.it/ProductDetail/Lite-On/LTV-816S/?qs=XpF7qU%252BvLkW8kf%252BAJLUsYA%3D%3D) | Transistor Output Optocouplers Optocoupler Phototrans | U52, U53, U101, U105, U352, U353, U354, U355
3 | H11A1 (https://www.mouser.it/ProductDetail/Vishay-Semiconductors/H11A1/?qs=wHZCbS0cJudwms5IsWl%252BJg%3D%3D) | Transistor Output Optocouplers Phototransistor Out | U502, U602, U657
1 | ULN2003V12S16-13 (https://www.mouser.it/ProductDetail/Diodes-Incorporated/ULN2003V12S16-13/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) | Darlington Transistors 7-Ch Relay Load Sink 20V 100mA Driver | U100
4 | MAX14933ASE+ (https://www.mouser.it/ProductDetail/Maxim-Integrated/MAX14933ASE%2b/?qs=vS28%252BL64B%2FqPTW%252BQJafmdA%3D%3D) | Digital Isolators 2 channel, each bidirectional, 2Mbps, 2.5kVrms digital isolator, NSOIC-16, -40C to +125C | U103, U104, U350, U351
2 | MIC2091-1YM5-TR (https://www.mouser.it/ProductDetail/Microchip-Technology-Micrel/MIC2091-1YM5-TR/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) | Power Switch ICs - Power Distribution 100mA Current Limiting Power Distribution Switch | U201, U202
1 | PIC16LF18345-I/SO (https://www.mouser.it/ProductDetail/Microchip-Technology/PIC16LF18345-I-SO/?qs=YvTEJ%2FLhu6VBIM1OLkQIIg%3D%3D) | 8-bit Microcontrollers - MCU 8-BIT MCU 14KB Flash 1K RAM, 10-BIT ADC | U102
1 | PIC24FJ1024GB610T-I/PT (https://www.mouser.it/ProductDetail/Microchip-Technology/PIC24FJ1024GB610T-I-PT/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) | 16-bit Microcontrollers - MCU 16-Bit MCU, 16 MIPS 1024K Flash, 32K RAM | U250
1 | 24CW1280T-I/OT (https://www.mouser.it/ProductDetail/Microchip-Technology/24CW1280T-I-OT/?qs=qSfuJ%252Bfl%2Fd6lIWZGGRvkYA%3D%3D) | EEPROM 128 Kbit I2C Serial EEPROM with Software Write Protection, Industrial Temp | U300
1 | MCP4716A0T-E/CH (https://www.mouser.it/ProductDetail/Microchip-Technology/MCP4716A0T-E-CH/?qs=ggQiQSXuoRWp4R%2FfYLl0zQ%3D%3D) | Digital to Analog Converters - DAC Sngl 10B NV DAC w/Ex Vref & I2C interface | U400
1 | MCP4716A1T-E/CH (https://www.mouser.it/ProductDetail/Microchip-Technology/MCP4716A1T-E-CH/?qs=ggQiQSXuoRX1efr49UstHQ%3D%3D) | Digital to Analog Converters - DAC Sngl 10B NV DAC w/Ex Vref & I2C interface | U405
2 | MCP1501T-40E/SN (https://www.mouser.it/ProductDetail/Microchip-Technology/MCP1501T-40E-SN/?qs=BA62vJVifGrdkKBGEAROIQ%3D%3D) | Voltage References High Prec Buffered Voltage Reference | U401, U406
2 | INA230AIRGTR (https://www.mouser.it/ProductDetail/Texas-Instruments/INA230AIRGTR/?qs=CKajpF%2FgJL%2FWNicekr0LSw%3D%3D) | Current Sense Amplifiers Prec Dig/Current/ Vltg/Power Monitor | U402, U404
2 | MAX5215GUA+T (https://www.mouser.it/ProductDetail/Maxim-Integrated/MAX5215GUA%2bT/?qs=LbY2dft4ljAy1MgOKk%2F6cQ%3D%3D) | Digital to Analog Converters - DAC 14 BIT LOW NOISE VERSION | U403, U407
2 | LT3080EQ#PBF (https://www.mouser.it/ProductDetail/Analog-Devices/LT3080EQPBF/?qs=hVkxg5c3xu8pN%2FlpJ3J3lQ%3D%3D) | LDO Voltage Regulators 1A Single Resistor Programmed Low Dropout Linear Regulator | U450, U550
2 | TL034CDR (https://www.mouser.it/ProductDetail/Texas-Instruments/TL034CDR/?qs=odmYgEirbwwjTyPpa7Wf9Q%3D%3D) | Precision Amplifiers Quad Enhanced JFET Low-Power Precision | U451, U551
3 | MAX15005AAUE+ (https://www.mouser.it/ProductDetail/Maxim-Integrated/MAX15005AAUE%2b/?qs=ZlLWvsADX%2FkwcSqERAEyng%3D%3D) | Switching Controllers 4.5V to 40V Input Automotive Flyback/Boost/SEPIC Power-Supply Controllers | U500, U600, U656
2 | LM2904M8-13 (https://www.mouser.it/ProductDetail/Diodes-Incorporated/LM2904M8-13/?qs=EDJ299gKAZTsUGqEBnd5aQ%3D%3D) | Operational Amplifiers - Op Amps OpAmp General Purpose | U501, U601

INTEGRATED CIRCUITS

CAPACITORS

RESISTORS

DIODES

TRANSISTORS

FUSES

MAGNETIC COMPONENTS

CONNECTORS

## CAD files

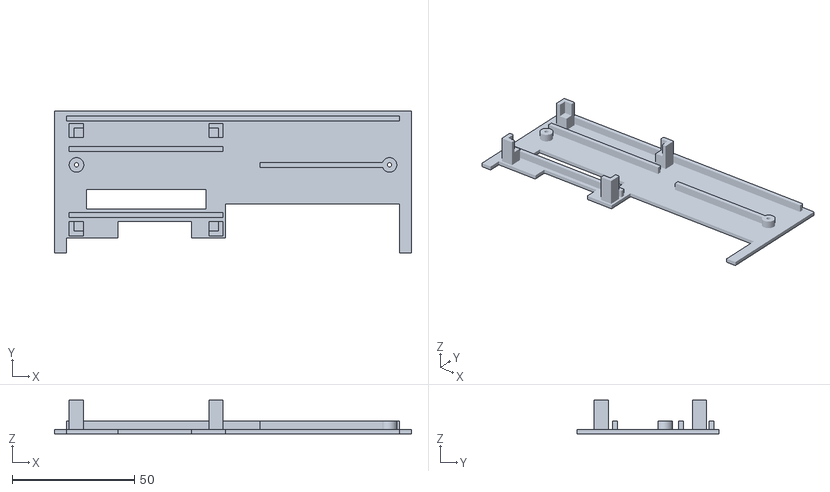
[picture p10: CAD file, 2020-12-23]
stl/DisplayHolder.stl
146.0 x 58.0 x 13.8

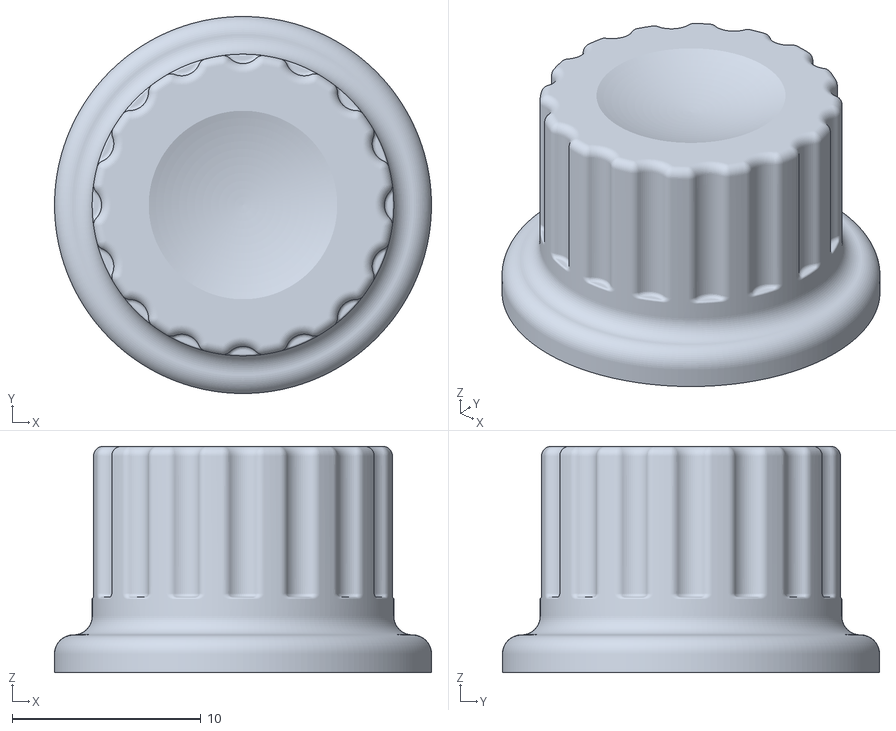
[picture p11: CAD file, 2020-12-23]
stl/Knob.stl
20.0 x 20.0 x 12.0

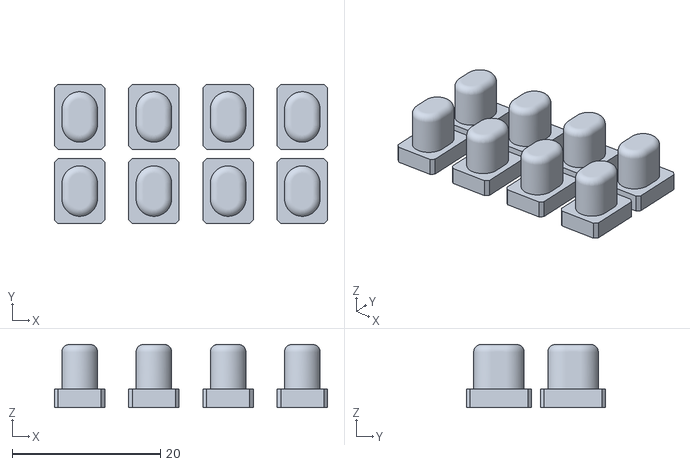
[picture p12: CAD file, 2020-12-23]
stl/Buttons.stl
36.8 x 18.8 x 8.50

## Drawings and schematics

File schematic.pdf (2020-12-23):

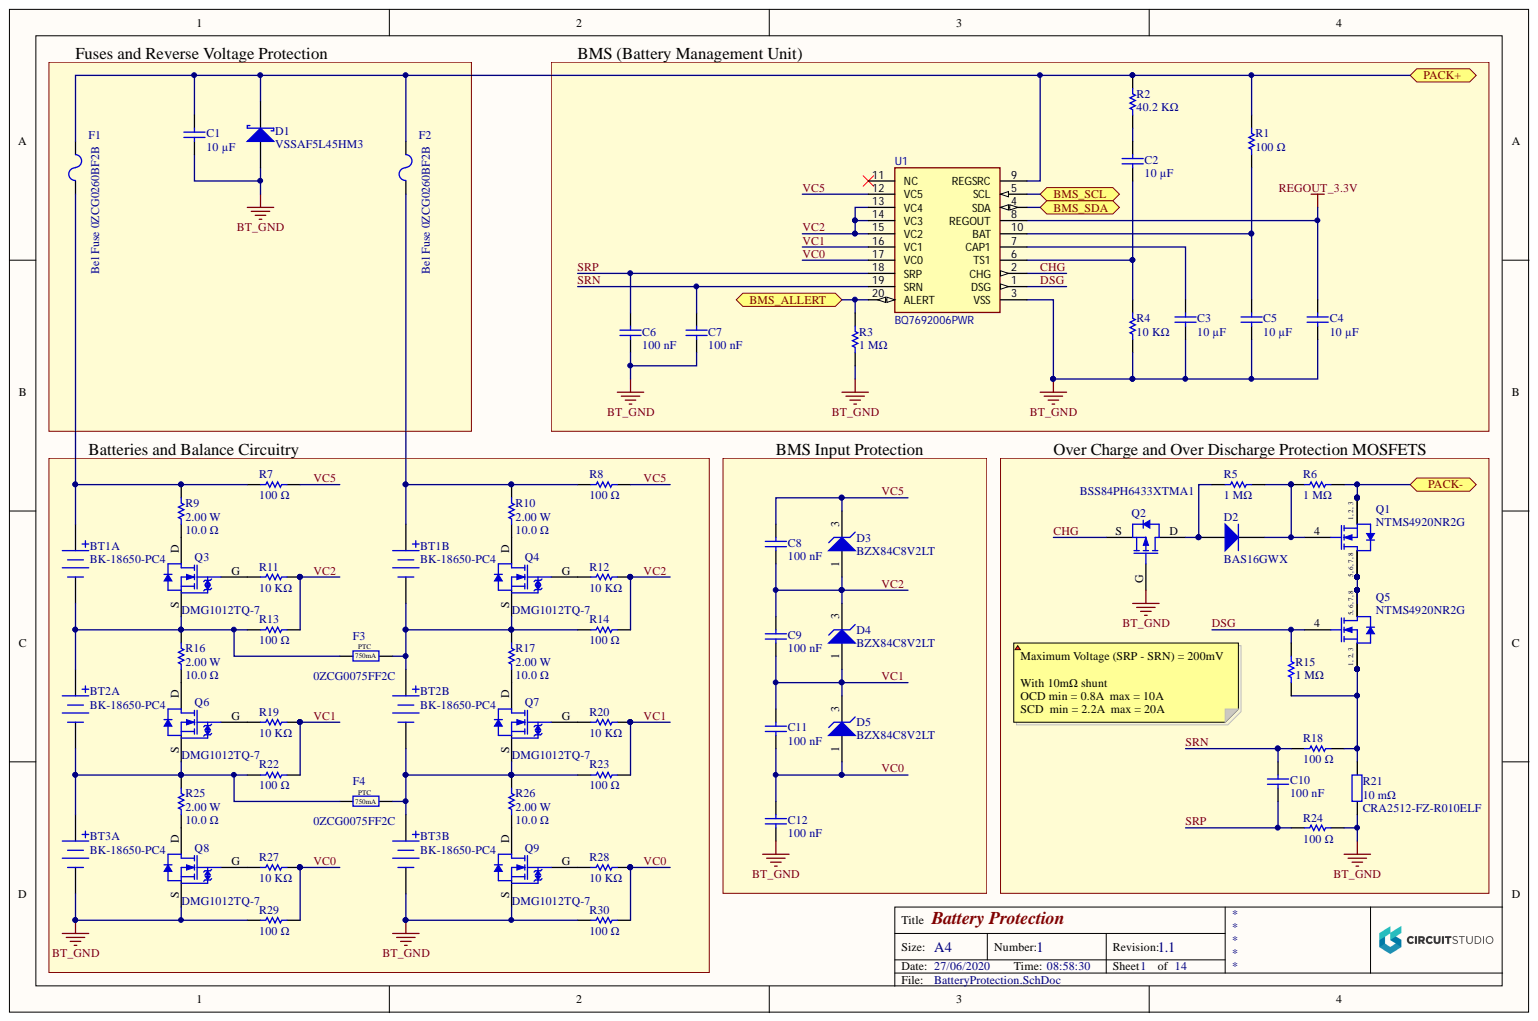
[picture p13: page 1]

R15 Maximum Voltage (SRP - SRN) = 200mV

Battery Protection Title | * *

A4 Size: | 1 Number: | 1.1 Revision:
Date: 27/06/2020 Time: 08:58:30 | | Sheet of

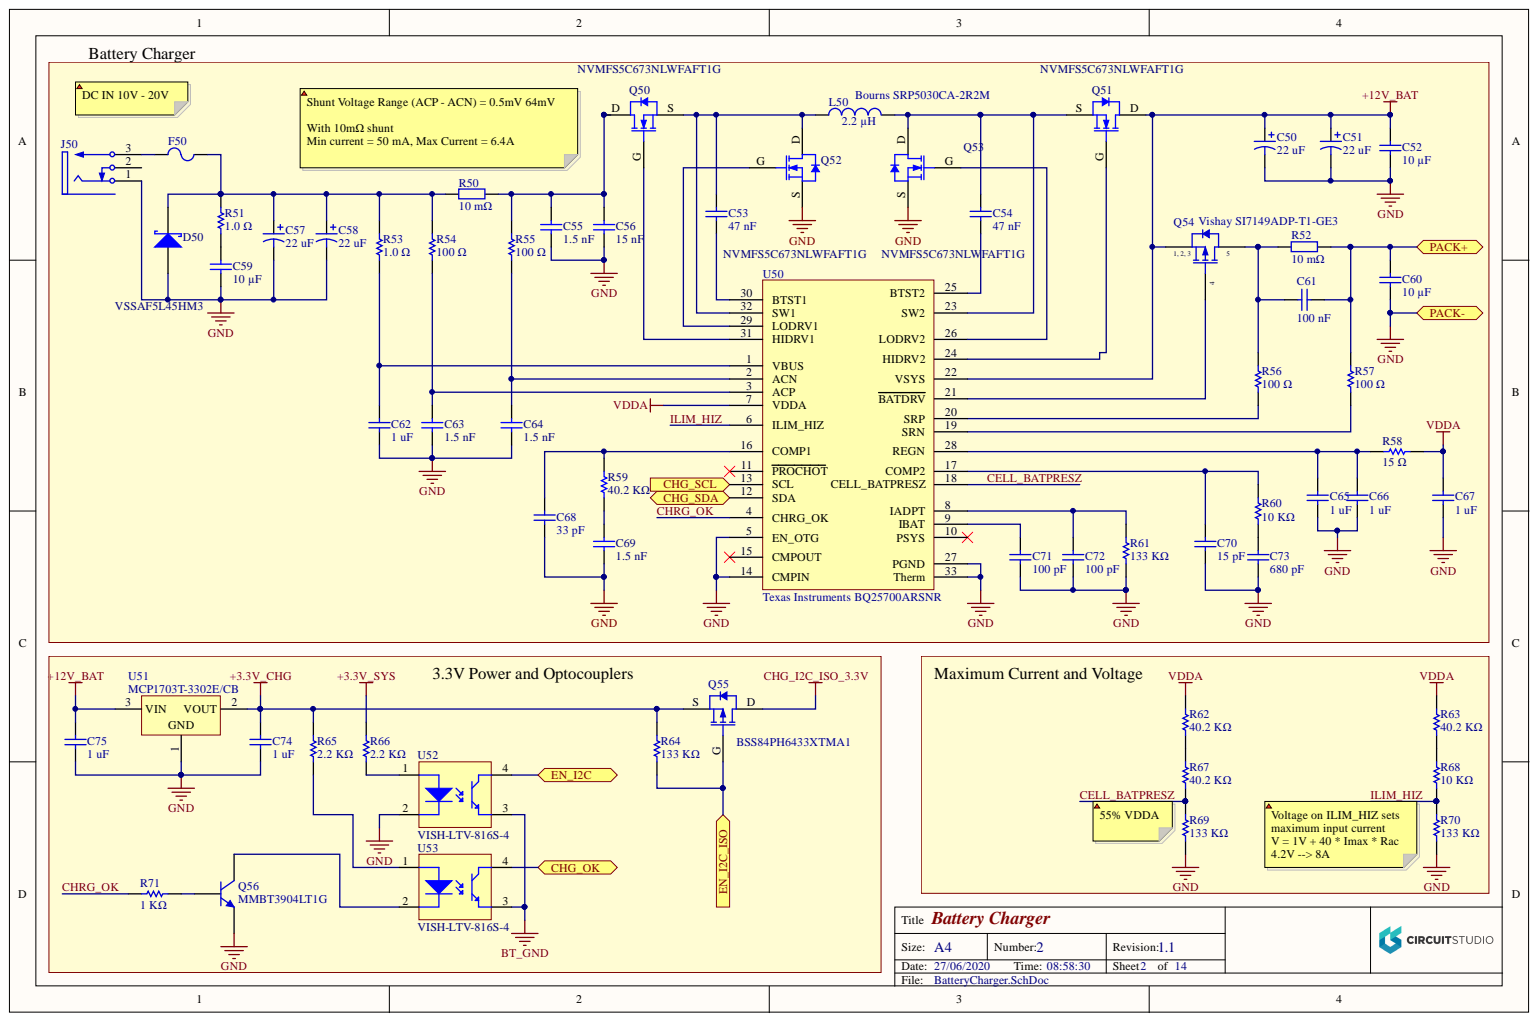
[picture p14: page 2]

With 10mΩ shunt
Min current = 50 mA, Max Current = 6.4A

C62 | | ACN 2

C63 | VDDA 7

R59 CHG_SCL 40.2 KΩ | PROCHOT 11

SDA 12 SCL 13 | CELL_BATPRESZ

A4 Size: | 2 Number: | 1.1 Revision:

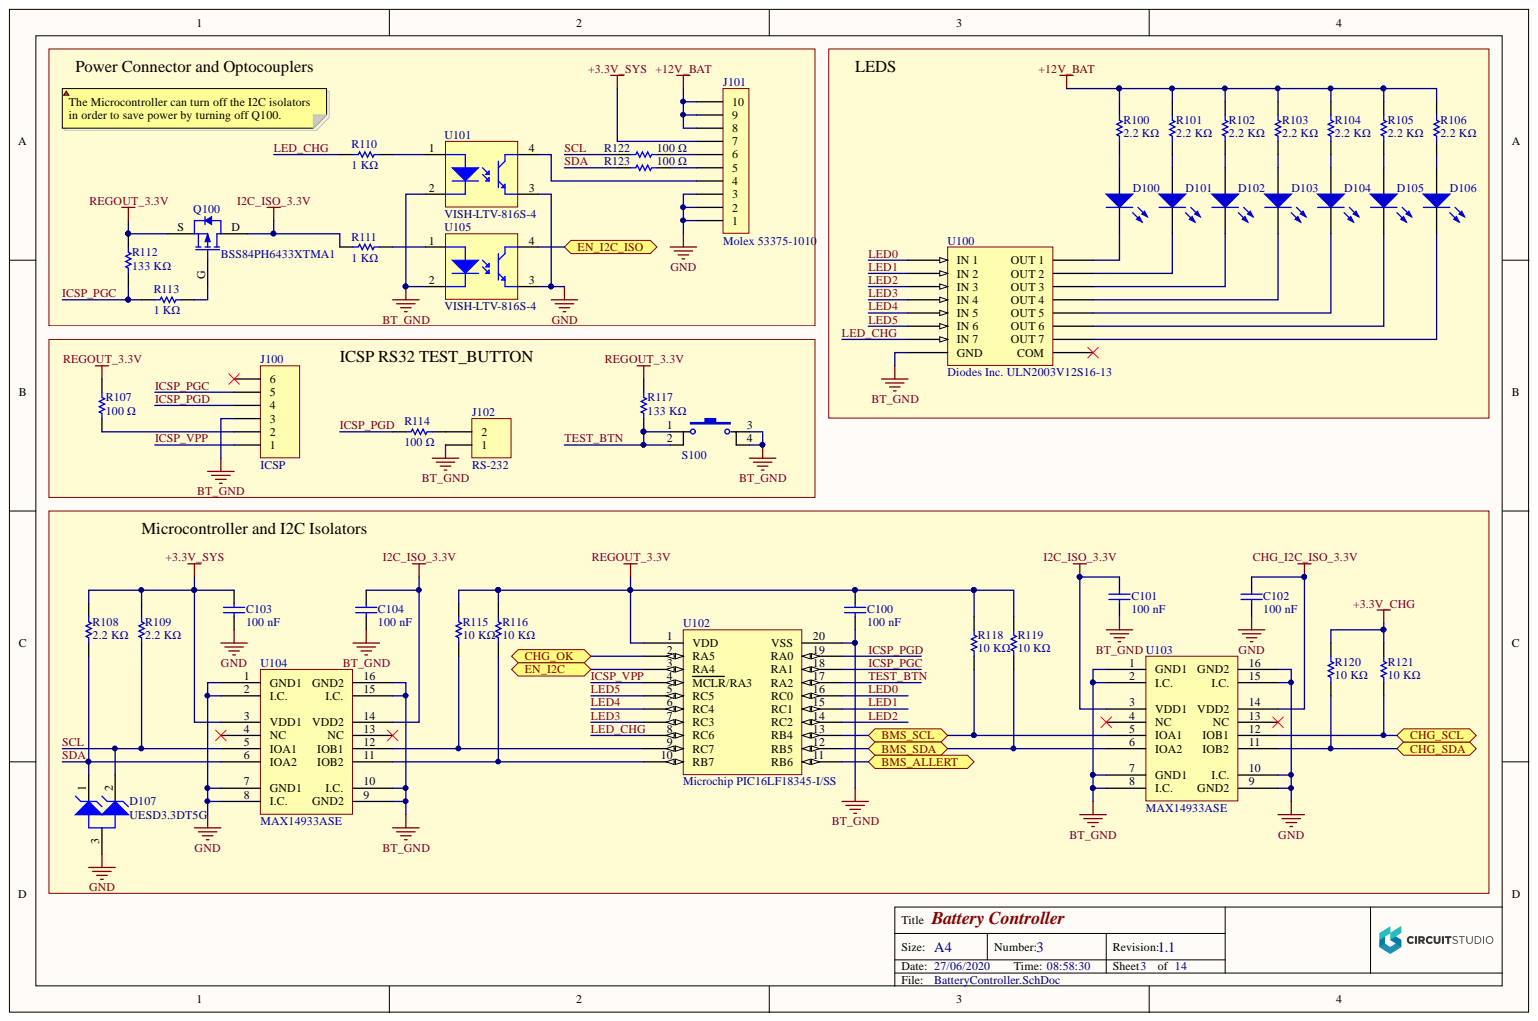
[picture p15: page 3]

Power Connector and Optocouplers

The Microcontroller can turn off the I2C isolators
in order to save power by turning off Q100.

Battery Controller Title

A4 Size: | 3 Number: | 1.1 Revision:

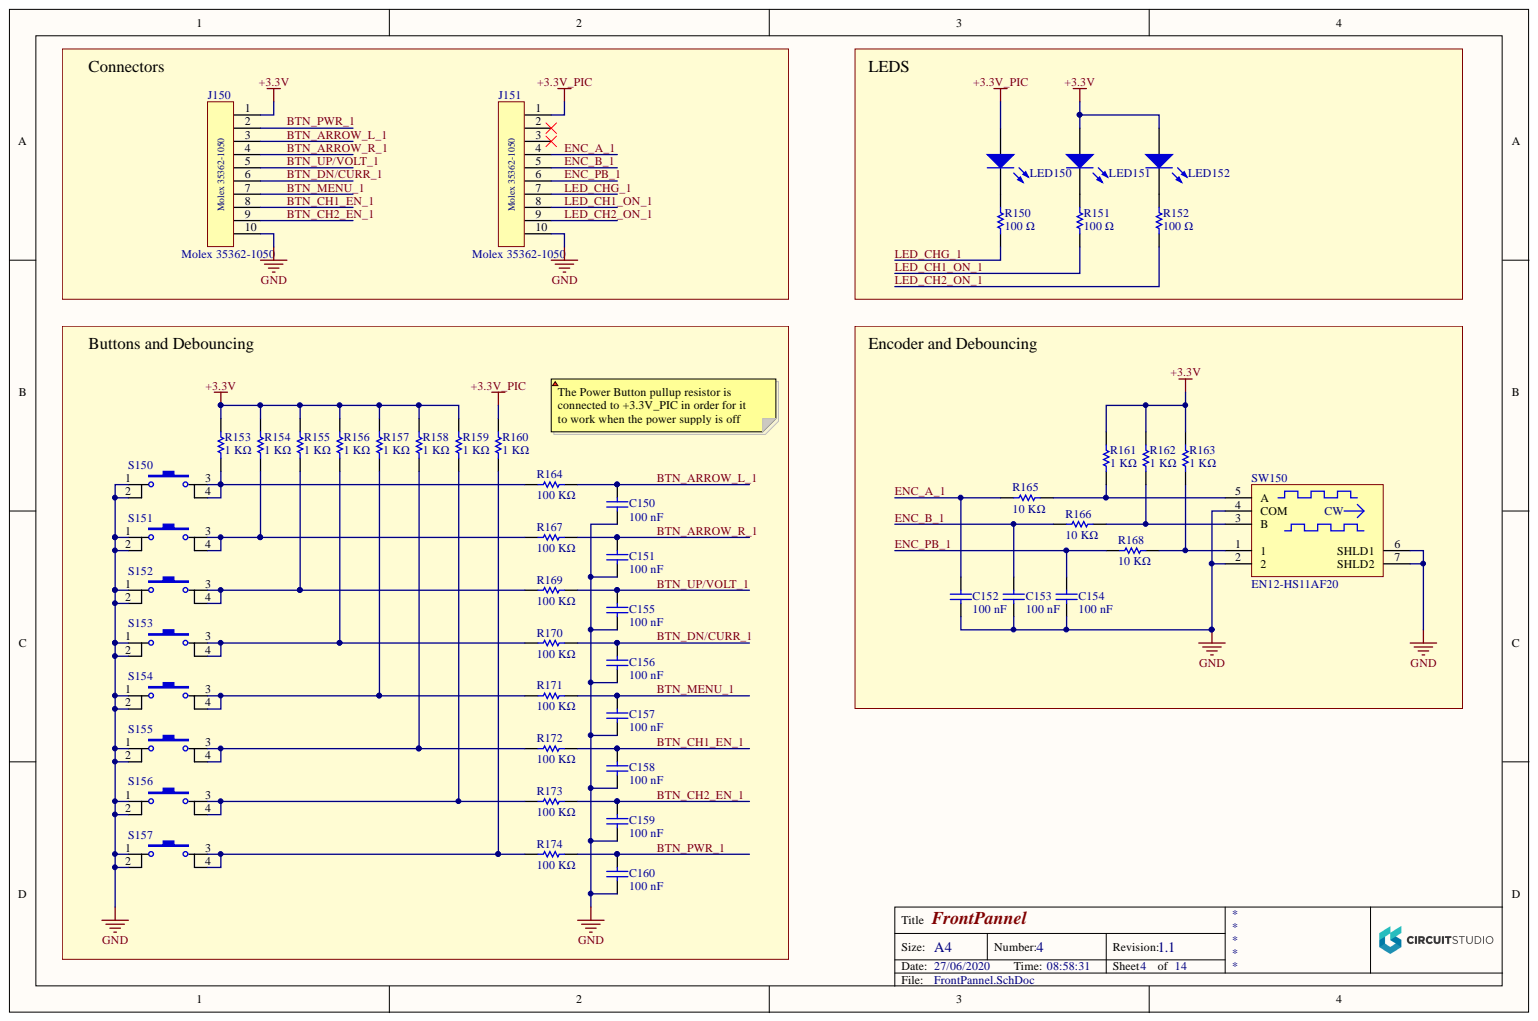
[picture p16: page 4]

The Power Button pullup resistor is
connected to +3.3V_PIC in order for it
to work when the power supply is off

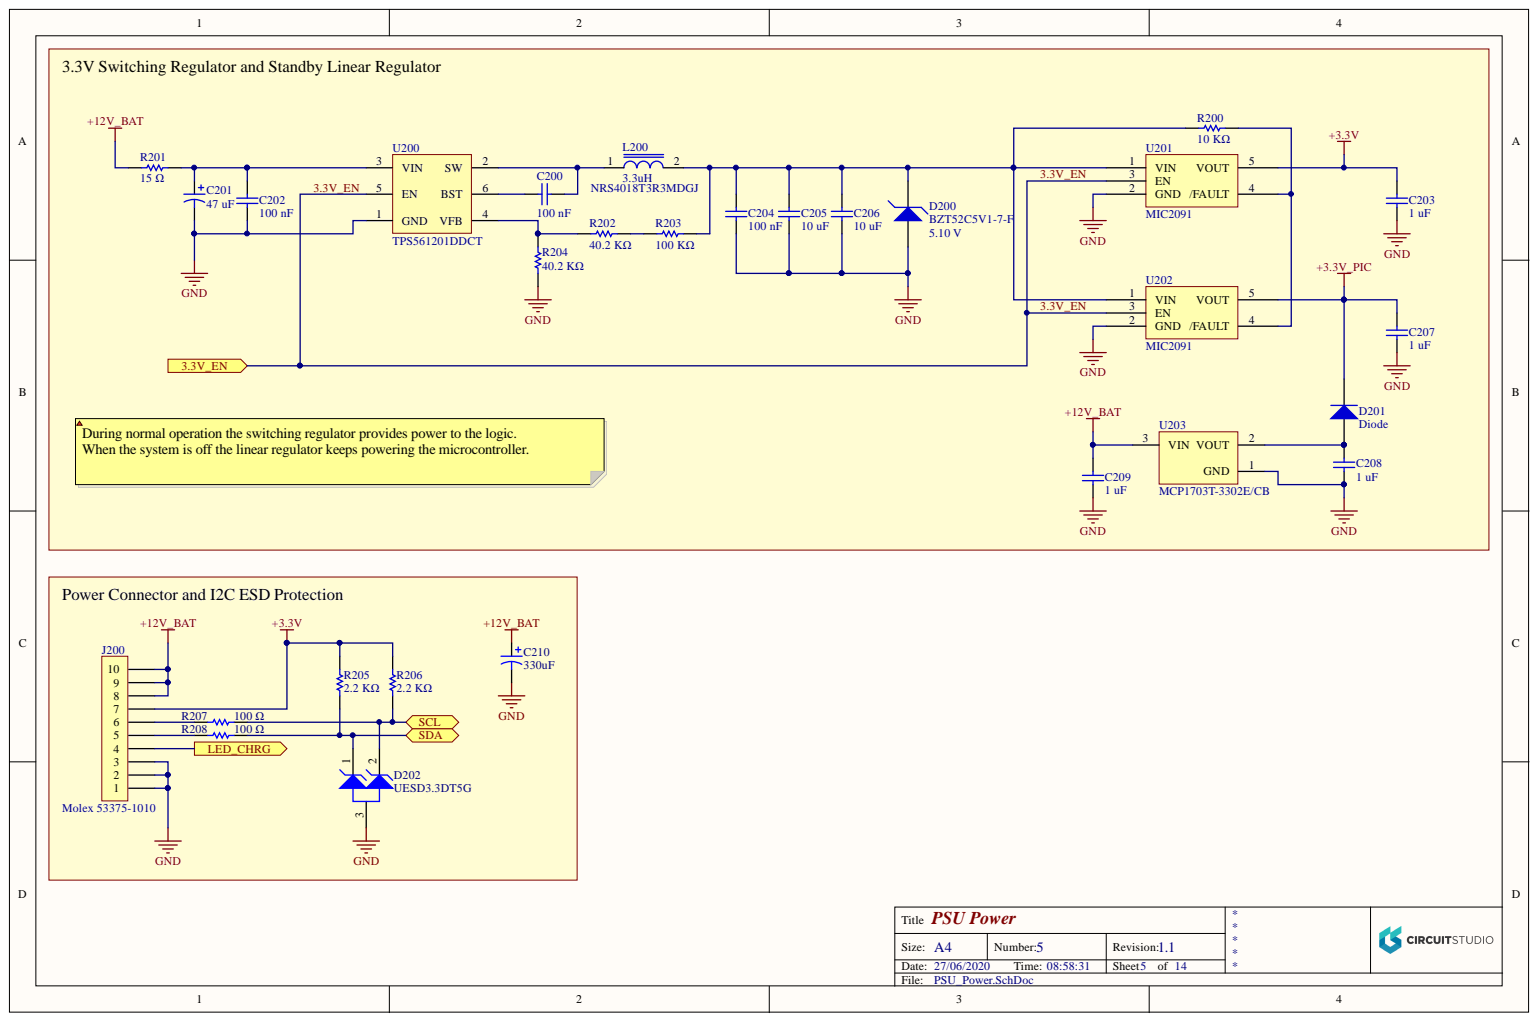
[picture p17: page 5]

3.3V Switching Regulator and Standby Linear Regulator

During normal operation the switching regulator provides power to the logic.
When the system is off the linear regulator keeps powering the microcontroller.

Power Connector and I2C ESD Protection

PSU Power Title | * *

A4 Size: | 5 Number: | 1.1 Revision:

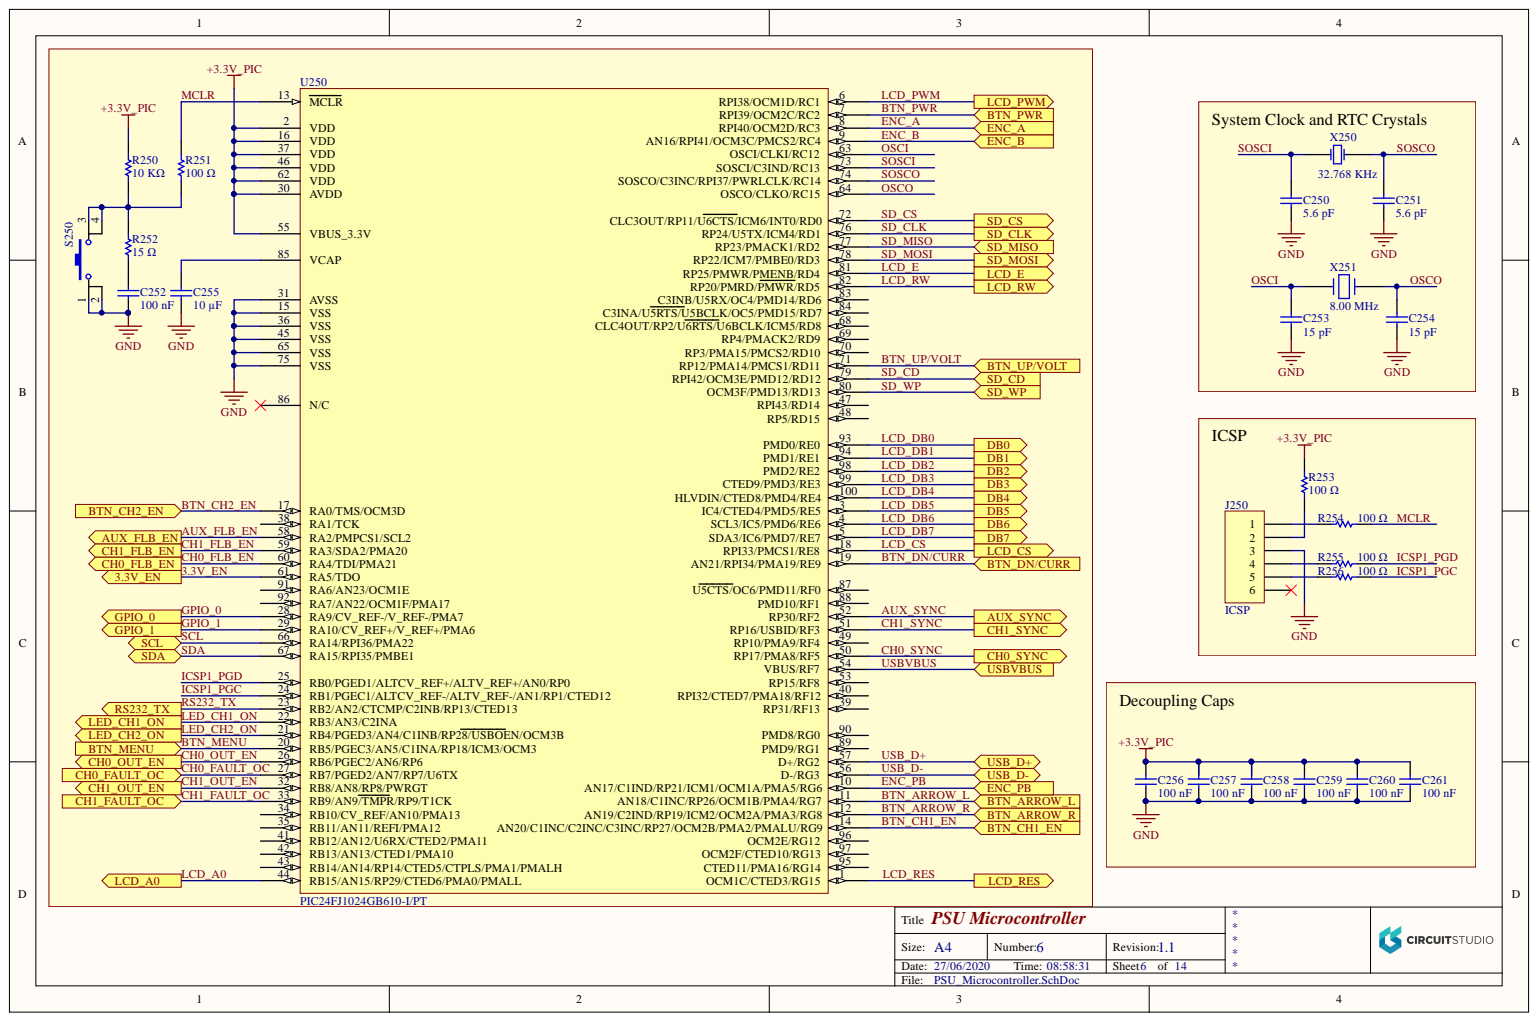
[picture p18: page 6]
PSU Microcontroller 6; 9 RPI32/CTED7/PMA18/RF12; 9 PMD8/RG0; _PIC 15 Ω; SOSCO OSCO; RTC Crystal; ing Caps; DB0 DB1 DB2 DB3 DB4 DB5 DB6 DB7 LCD

System Clock and

1 6
3 7
4 6

1 5
3 6
4 5
6 5

A4 Size: | N umber: | 1.1 Rev i s i o n :

/ / T ime: : : | | Sheet o f

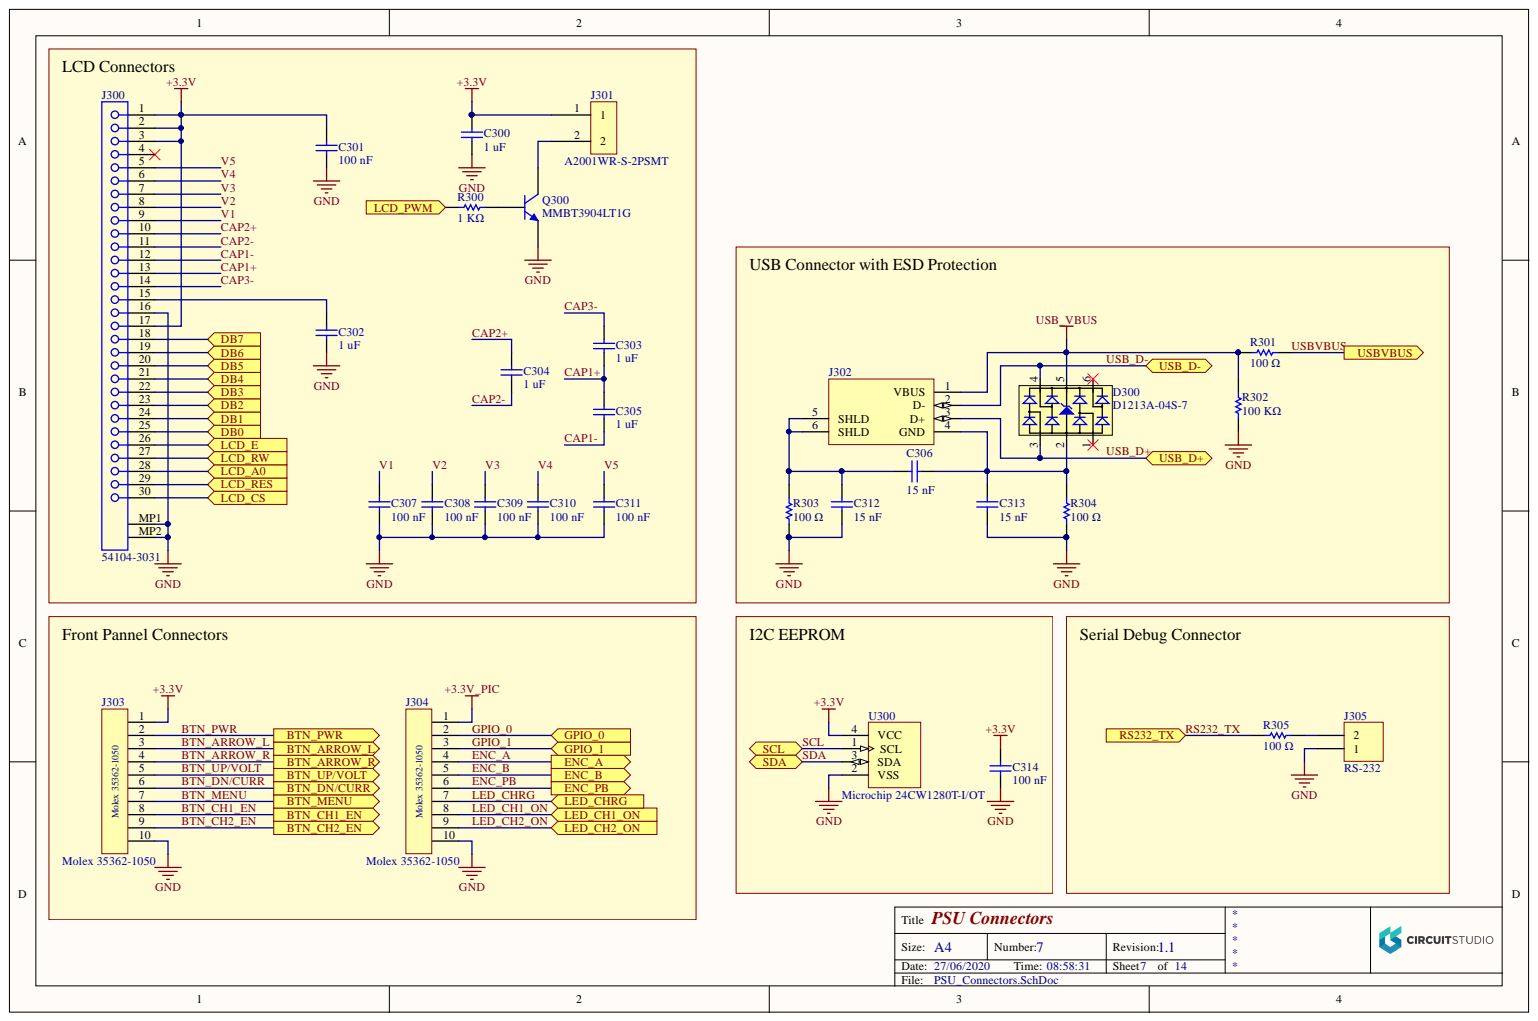
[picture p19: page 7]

USB Connector with ESD Protection

PSU Connectors Title | * *

A4 Size: | 7 Number: | 1.1 Revision:

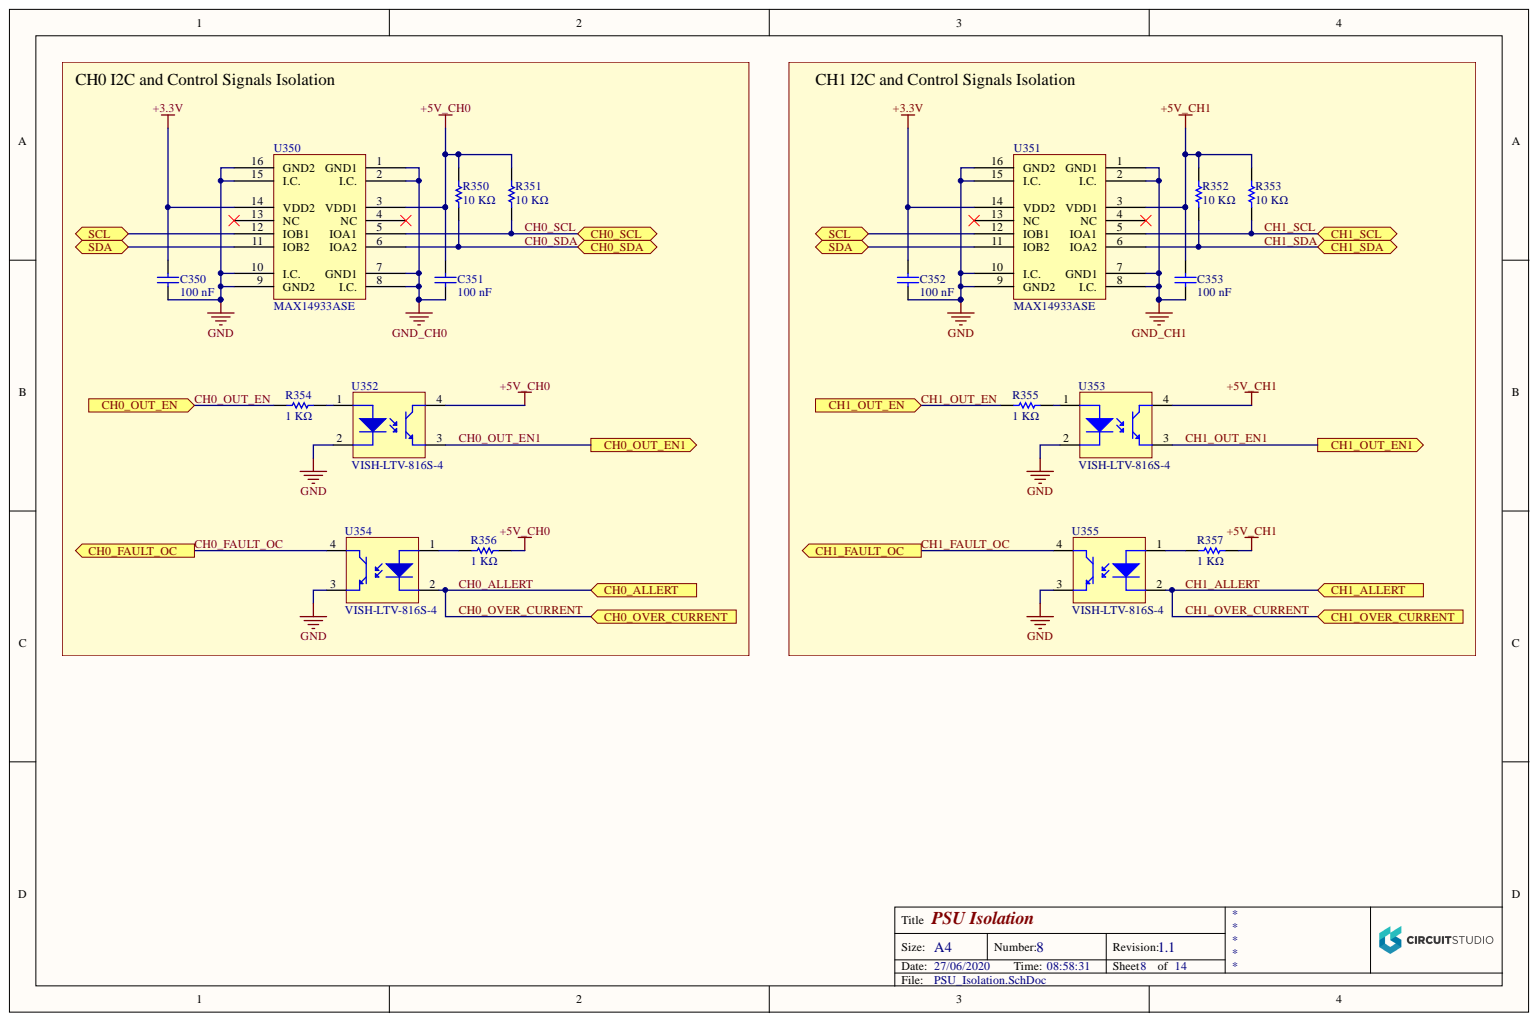
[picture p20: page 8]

PSU Isolation Title | * *

A4 Size: | 8 Number: | 1.1 Revision:

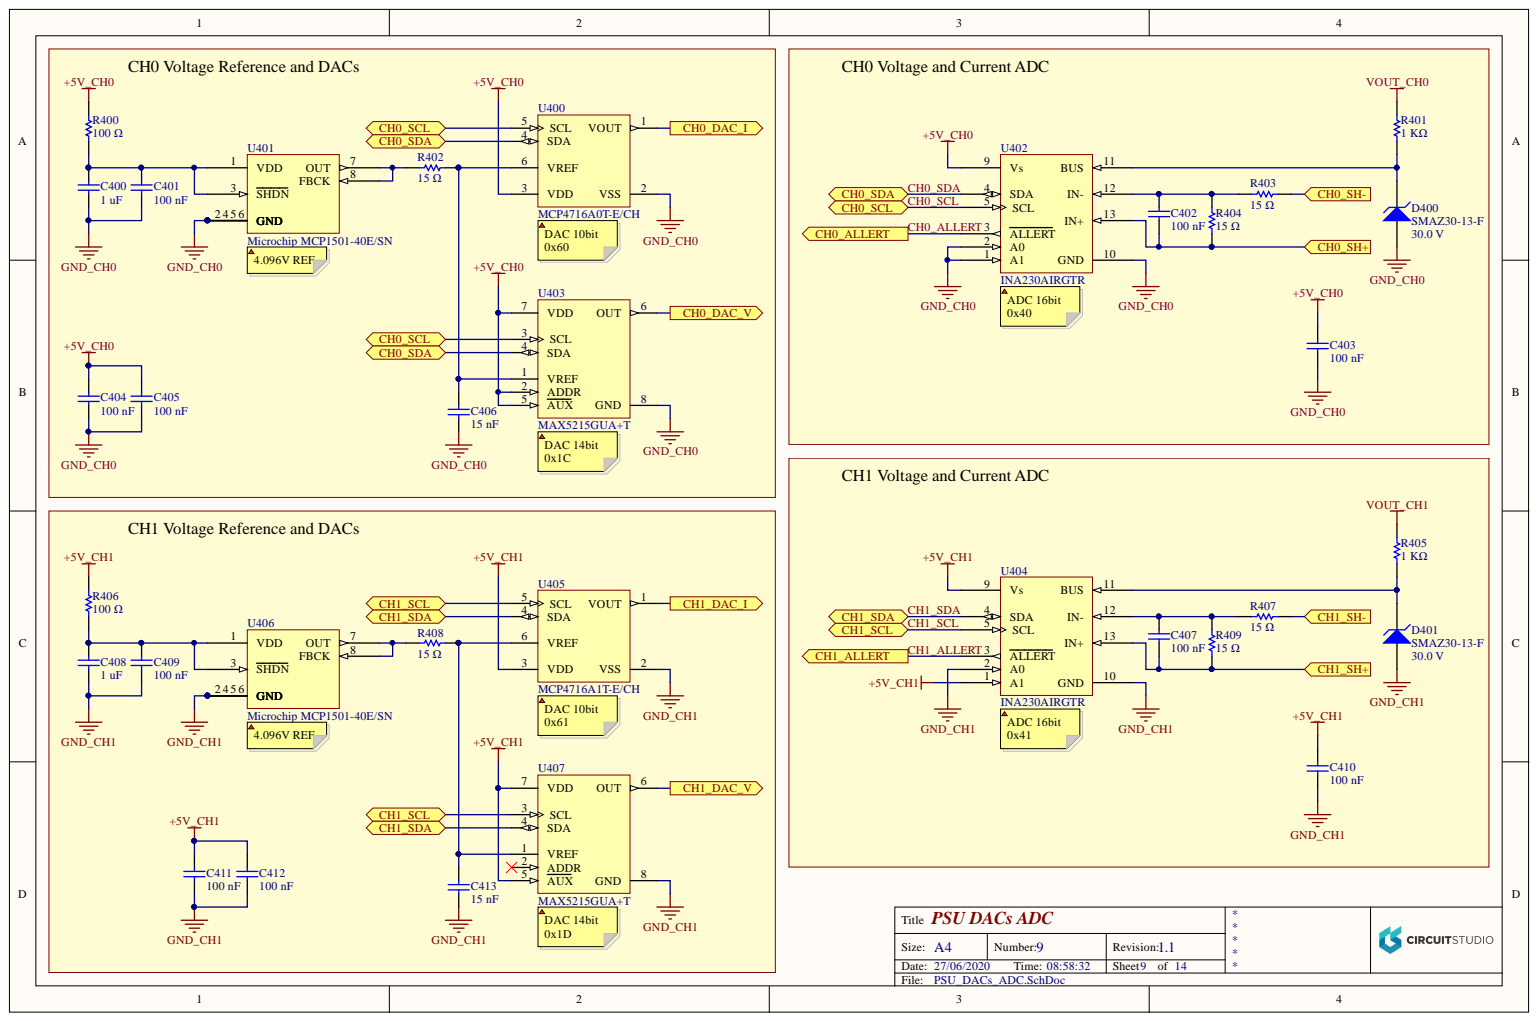
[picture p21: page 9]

CH1 Voltage and Current ADC

CH1 Voltage Reference and DACs

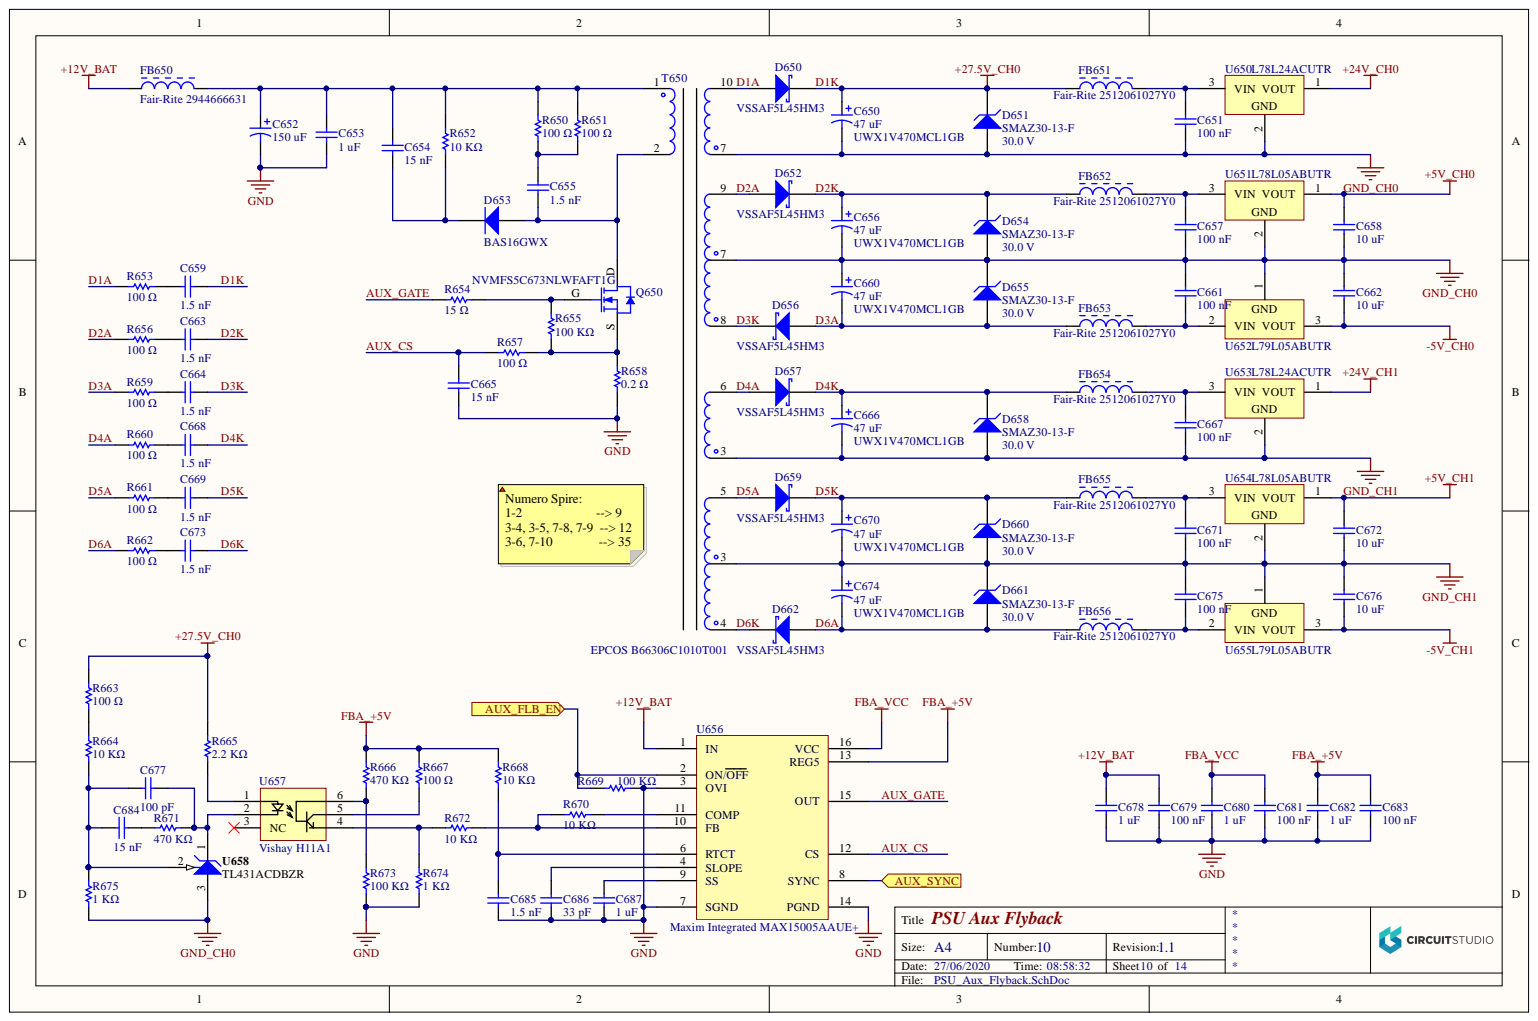
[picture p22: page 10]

PSU Aux Flyback Title | * *

A4 Size: | 10 Number: | 1.1 Revision:

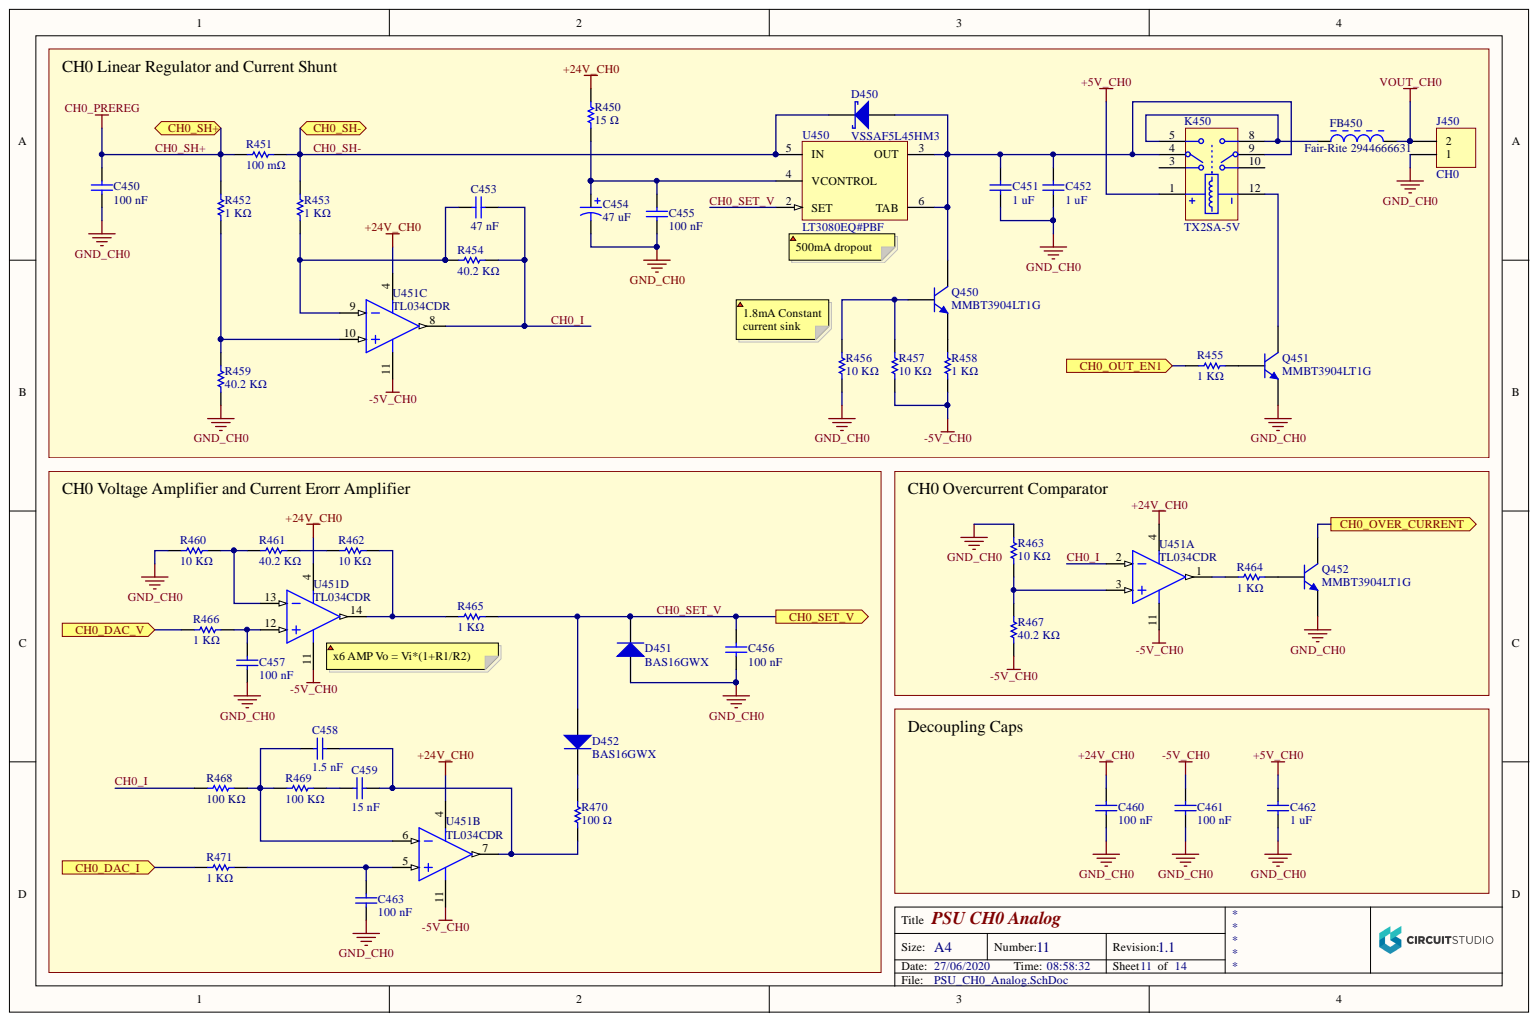
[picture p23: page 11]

CH0 Linear Regulator and Current Shunt +24V_CH0

CH0 Voltage Amplifier and Current Erorr Amplifier

PSU CH0 Analog Title | * *

A4 Size: | 11 Number: | 1.1 Revision:

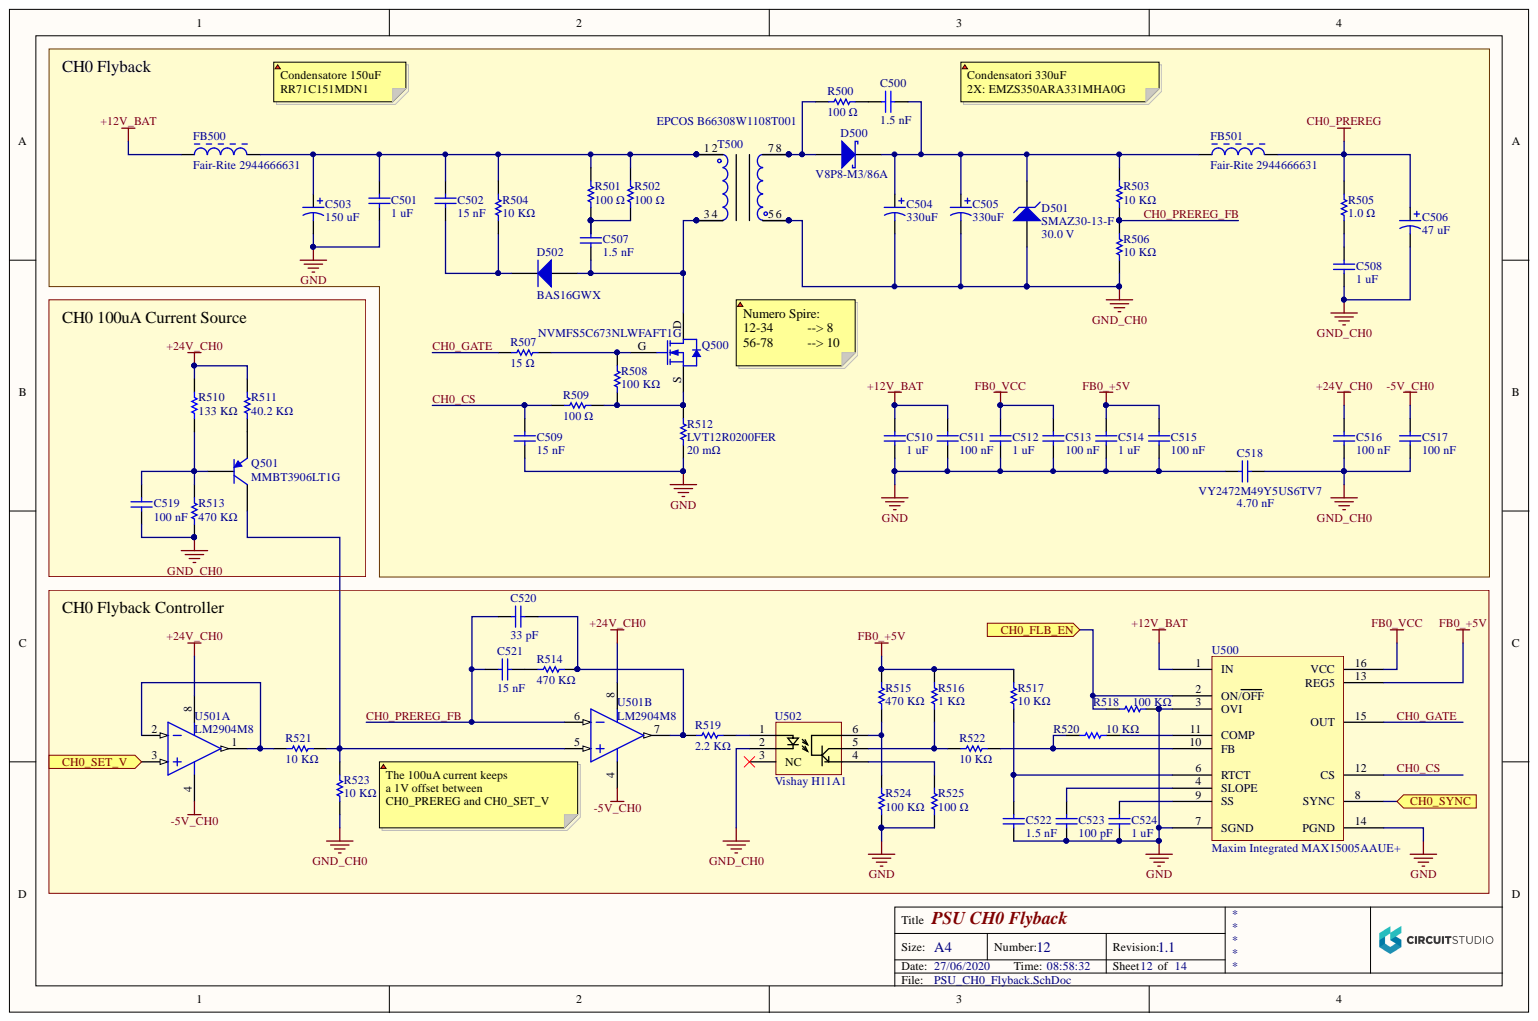
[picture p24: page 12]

R520 10 KΩ | FB 10 COMP 11

PSU CH0 Flyback Title | * *

A4 Size: | 12 Number: | 1.1 Revision:


CH1 Linear Regulator and Current Shunt +24V_CH1

CH1 Voltage Amplifier and Current Erorr Amplifier

PSU CH1 Analog Title | * *

A4 Size: | 13 Number: | 1.1 Revision:


PSU CH1 Flyback Title | * *

A4 Size: | 14 Number: | 1.1 Revision:

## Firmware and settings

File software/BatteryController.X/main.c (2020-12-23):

/* 
 * File:    main.c
 * Author:  Manuel
 * Date:    26/06/2020
 * Device:  PIC16LF18346
 * Rev:     1.2 2020
 * 
 * Firmware for the Battery Board
 * 
 * TMR0:
 *      1 millisecond tick
 *      interrupt every 60 seconds
 *      used by the time library
 * 
 * TMR3:
 *      1 second Interrupt
 *      to wake up the microcontroller every second during sleep
 * 
 * WATCHDOG:
 *      enabled with 2 second period
 */

#include <mcc.h>
#include <math.h>
#include <stdbool.h>
#include <stdint.h>
#include "leds.h"
#include "time.h"
#include "bms.h"
#include "chg.h"
#include "i2cMaster.h"
#include "i2cSlave.h"
#include "types.h"

#pragma warning disable 520     //Function is never called
#pragma warning disable 2053    //Function is never called
#pragma warning disable 1510    //Function appears in multiple call graphs and has been dupplicated

#define _LOG_DATA       true
#define _LOG_RAW        true
#define _LOG_INTERVALL  (5*60)  //Interval between log points in seconds


//Global variables
static volatile bool runUpdateLogic = true;    //Flag set by the interrupt routine every second
static volatile bool extBtnPressed = false;    //Flag set when the external button is pressed
static state_t state = e_STATE_INIT;

//Interrupt service routines
void ISR_Interrupt_1Sec(void);
void ISR_ExtBtn(void);
void ISR_PSU_On(void);
void ISR_ExternalPower(void);

//Static functions
static void LogData(void);


void main(void){
    
    //Initialize device
    SYSTEM_Initialize();
    TIME_Initialize();
    LEDS_Initialize();
    
    //Set interrupt handler functions
    TMR0_SetInterruptHandler(TIME_ISR_Timer);           //60 sec Interrupt
    TMR3_SetInterruptHandler(ISR_Interrupt_1Sec);       //1s interrupt
    INT_SetInterruptHandler(ISR_ExtBtn);                //External button interrupt
    IOCBF6_SetInterruptHandler(BMS_AlertISR);           //Alert PIN interrupt
    IOCAF4_SetInterruptHandler(ISR_PSU_On);             //Power supply switched ON
    IOCAF5_SetInterruptHandler(ISR_ExternalPower);      //External power connected

    //Setup SLEEP mode
    CPUDOZEbits.IDLEN = 1;  //During SLEEP CPU clock is halted but the peripheral clock continues to run
    
    //Enable Global and Peripheral Interrupts
    INTERRUPT_GlobalInterruptEnable();
    INTERRUPT_PeripheralInterruptEnable();
    PIE0bits.IOCIE = 1; 
    
    printf("Battery Controller 1.1\n");
    printf("Date: %s\n\n", __DATE__);
    
    //Wait for power to stabilize
    IO_3V3_ENABLE_SetLow(); //Enable Power to I2C bus
    TIME_Delay_ms(1000);
    CLRWDT();
    
    //Initialize BMS IC
    LEDS_SetState(e_LED_FULL, true);
    LEDS_SetState(e_LED_BT1_BL, true);
    printf("BMS Initialization\n");
    while(!BMS_Initialize()){
        printf("BMS Initialization failed\n");
        TIME_Delay_ms(500);
        CLRWDT();
    }
    LEDS_SetToDefault();
    
    //Initialize CHG IC
    LEDS_SetState(e_LED_FULL, true);
    LEDS_SetState(e_LED_BT2_BL, true);
    printf("CHG Initialization\n");
    while(!CHG_Initialize()){
        printf("CHG Initialization failed\n");
        BMS_Update(state);
        TIME_Delay_ms(500);
        CLRWDT();
    }
    LEDS_SetToDefault();
    
    
    //Main loop
    while(1){
        bool keepRunning = state != e_STATE_IDLE;

        //Update BMS state and variables
        BMS_Update(state);
 
        //Update CHG state
        CHG_Update(state);
        
        //Show battery level
        if(extBtnPressed){
            extBtnPressed = false;
            LEDS_ShowBatteryLevel();
        }
        
        //Log data during charge and discharge
        if(state != e_STATE_IDLE)
            LogData();
        
        //Update LED state
        keepRunning |= LEDS_Update();
        
        if(runUpdateLogic){
            runUpdateLogic = false;

            //Enter low power mode
            if(!keepRunning){
                LEDS_SetState(e_LED_BT1_CH, false);
                asm("SLEEP");
                LEDS_SetState(e_LED_BT1_CH, true);
            }
        }
        
        
        //Change state
        bool PowerSupplyOn  = !IO_EN_I2C_GetValue();
        bool ChargerPresent = !IO_CHG_OK_GetValue();

        switch(state){
            case e_STATE_INIT:
                IO_3V3_ENABLE_SetHigh();        //Disable Power to I2C bus
                state = e_STATE_IDLE;
                break;

            case e_STATE_IDLE:
                if(ChargerPresent){
                    IO_3V3_ENABLE_SetLow();     //Enable Power to I2C bus
                    LEDS_SetToDefault();        //Turn off LEDs
                    state = e_STATE_CHARGING;
                }
                else if(PowerSupplyOn){
                    IO_3V3_ENABLE_SetLow();     //Enable Power to I2C bus
                    LEDS_SetToDefault();        //Turn off LEDs
                    state = e_STATE_DISCHARGING;
                }
                break;

            case e_STATE_CHARGING:
                if(!ChargerPresent){
                    CHG_EnableCharger(false);   //Disable charger
                    IO_3V3_ENABLE_SetHigh();    //Disable Power to I2C bus
                    LEDS_SetToDefault();        //Turn off LEDs
                    state = e_STATE_IDLE;
                }
                break;

            case e_STATE_DISCHARGING:
                if(!PowerSupplyOn || ChargerPresent){
                    IO_3V3_ENABLE_SetHigh();    //Disable Power to I2C bus
                    LEDS_SetToDefault();        //Turn off LEDs
                    state = e_STATE_IDLE;
                }
                break;
        }
        
        CLRWDT();
    }
}

static void LogData(void){
#if (_LOG_DATA == true)
    static int32_t last = _LOG_INTERVALL / 2;
    uint32_t time = TIME_Seconds();
    
    if(time - last >= _LOG_INTERVALL){
        last = time;
        
        float v1 = (float)BMS_GetCellVoltage(1) / 1000.0f;
        float v2 = (float)BMS_GetCellVoltage(2) / 1000.0f;
        float v3 = (float)BMS_GetCellVoltage(3) / 1000.0f;
        float current = (float)BMS_GetCurrent() / 1000.0f;
        float energy = (float)BMS_GetEnergy() / 1000.0f;
        float capacity = (float)BMS_GetCapacity() / 1000.0f;
        
#if (_LOG_RAW == true)
        printf("%.3f;%.3f;%.3f;%.3f;%d;%.3f;%.3f\n", v1, v2, v3, current, BMS_GetSOC(), energy, capacity);
#else
        printf("v1:%dmV v2:%dmV v3:%dmV  i:%dmA SOC:%d%% T:%d*C En:%ldmWh Ca:%ldmWh\n",
            BMS_GetCellVoltage(1), BMS_GetCellVoltage(2), BMS_GetCellVoltage(3),
            BMS_GetCurrent(), BMS_GetSOC(), BMS_GetTemperature(),
            BMS_GetEnergy(), BMS_GetCapacity());
#endif  
    }
#endif
}

/*
 * ISR called by the overflow of timer3 every 1 sec
 */
void ISR_Interrupt_1Sec(void){
    runUpdateLogic = true;
}

/*
 * ISR called when the button is pressed
 */
void ISR_ExtBtn(void){
    extBtnPressed = true;
}

/*
 * ISR called when the power supply is turned on
 */
void ISR_PSU_On(void){
    runUpdateLogic = true;
}

/*
 * ISR called when external power is connected
 */
void ISR_ExternalPower(void){
    runUpdateLogic = true;
}

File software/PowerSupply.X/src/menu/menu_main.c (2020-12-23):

/* 
 * File:    menu_main.c
 * Author:  Manuel
 * Date:    10/10/2018
 * 
 * Comments: Main page of the menu
 */

#include "mcc.h"
#include "menu.h"
#include "hardware/inputs.h"
#include "hardware/power.h"
#include "debug/errors.h"
#include <stdio.h>

static void Initialize(void*);
static void Redraw(void);
static void ProcessInput(uint8_t buttons, int8_t encoder);
static void Tick(int64_t millis);
static MenuFloat_t* GetSelectedMenuFloat(void);


static char date[22];
static const char* title = "                     ";
MenuPage_t menu_main = {&Initialize, &Redraw, &ProcessInput, &Tick, true, &title, e_NORMAL};

static uint8_t selectedChannel = 0;
static bool isVoltageSelected = true;

//Initialize menu
static void Initialize(void* arg){
   
}

//Redraw the screen
static void Redraw(void){
    
    GLCD_VLine(_LCD_HALF_W - 1, 7, _LCD_HEIGHT - 8, true);
    GLCD_VLine(_LCD_HALF_W,     7, _LCD_HEIGHT - 8, true);
    GLCD_HLine(0,              42, _LCD_WIDTH,      true);
    
    //Draw channel 1
    GLCD_VLine(15, 8, 7, true);
    GLCD_HLine(0, 15, 16, true);
    GLCD_SetFont(_FONT_4x5);
    GLCD_SetTextModeInverted(selectedChannel == 1);
    GLCD_PrintString(1, 9, "CH1");
    GLCD_SetTextModeInverted(false);
    GLCD_PrintString(43, 47, "SET V");
    GLCD_PrintString(43, 59, "SET A");
    
    GLCD_SetFont(_FONT_8x11);
    GLCD_printNumF(2, 17, _GLOBAL_VAR_CH(1).senseVoltage, 6, 3, '.', ' ');
    GLCD_printNumF(11, 29, _GLOBAL_VAR_CH(1).senseCurrent, 5, 3, '.', ' ');
    GLCD_PrintString(53, 17, "V");
    GLCD_PrintString(53, 29, "A");
    GLCD_SetFont(_FONT_6x9);
    int VoltageCH1CursorPos = (selectedChannel == 1 && isVoltageSelected == true)  ? _GLOBAL_VAR_CH(1).setVoltage.selectedDigit : _NO_CURSOR;
    int CurrentCH1CursorPos = (selectedChannel == 1 && isVoltageSelected == false) ? _GLOBAL_VAR_CH(1).setCurrent.selectedDigit : _NO_CURSOR;
    GLCD_printNumWithCursorF(2, 44, _GLOBAL_VAR_CH(1).setVoltage.value, 6, 3, '.', ' ', VoltageCH1CursorPos);
    GLCD_printNumWithCursorF(9, 55, _GLOBAL_VAR_CH(1).setCurrent.value, 5, 3, '.', ' ', CurrentCH1CursorPos);
    
    
    //Draw channel 2
    GLCD_VLine(80, 8, 7, true);
    GLCD_HLine(65, 15, 16, true);
    GLCD_SetFont(_FONT_4x5);
    GLCD_SetTextModeInverted(selectedChannel == 2);
    GLCD_PrintString(66, 9, "CH2");
    GLCD_SetTextModeInverted(false);
    GLCD_PrintString(109, 47, "SET V");
    GLCD_PrintString(109, 59, "SET A");
    
    GLCD_SetFont(_FONT_8x11);
    GLCD_printNumF(67, 17, _GLOBAL_VAR_CH(2).senseVoltage, 6, 3, '.', ' ');
    GLCD_printNumF(76, 29, _GLOBAL_VAR_CH(2).senseCurrent, 5, 3, '.', ' ');
    GLCD_PrintString(119, 17, "V");
    GLCD_PrintString(119, 29, "A");
    GLCD_SetFont(_FONT_6x9);
    int VoltageCH2CursorPos = (selectedChannel == 2 && isVoltageSelected == true)  ? _GLOBAL_VAR_CH(2).setVoltage.selectedDigit : _NO_CURSOR;
    int CurrentCH2CursorPos = (selectedChannel == 2 && isVoltageSelected == false) ? _GLOBAL_VAR_CH(2).setCurrent.selectedDigit : _NO_CURSOR;
    GLCD_printNumWithCursorF(67, 44, _GLOBAL_VAR_CH(2).setVoltage.value, 6, 3, '.', ' ', VoltageCH2CursorPos);
    GLCD_printNumWithCursorF(74, 55, _GLOBAL_VAR_CH(2).setCurrent.value, 5, 3, '.', ' ', CurrentCH2CursorPos);
    
    //Print date
    GLCD_SetFont(_FONT_4x5);
    GLCD_PrintString(1, 1, date);
}


//Handle inputs
static void ProcessInput(uint8_t buttons, int8_t encoder){
    bcdTime_t time;
    while (RTCC_TimeGet(&time) == false);
    
    //Process buttons
    switch(buttons){
        case _BUTTON_ENCH1:
            _GLOBAL_VAR_CH(1).enabled = !_GLOBAL_VAR_CH(1).enabled;
            break;
            
        case _BUTTON_ENCH2:
            _GLOBAL_VAR_CH(2).enabled = !_GLOBAL_VAR_CH(2).enabled;
            break;
            
        case _BUTTON_LEFT:
            MENU_ChangeSelectedDigitMenuFloat(GetSelectedMenuFloat(), 1);
            break;
            
        case _BUTTON_RIGHT:
            MENU_ChangeSelectedDigitMenuFloat(GetSelectedMenuFloat(), -1);
            break;
            
        case _BUTTON_UP_V:
            if(isVoltageSelected)
                selectedChannel = (selectedChannel + 1) % 3;
            else{
                isVoltageSelected = true;
                if(selectedChannel == 0)
                    selectedChannel = 1;
            }
            break;
            
        case _BUTTON_DW_I:
            if(!isVoltageSelected)
                selectedChannel = (selectedChannel + 1) % 3;
            else{
                isVoltageSelected = false;
                if(selectedChannel == 0)
                    selectedChannel = 1;
            }
            break;
            
        case _BUTTON_MENU:
            MENU_Push(&menu_menu, NULL);
            break;
        
        default:
            break;
    }
    
    //Process encoder
    if(encoder){
        MENU_IncrementMenuFloat(GetSelectedMenuFloat(), encoder);
    }
    
    menu_main.outOfDate = true;
}

static void Tick(int64_t millis){
    //Update date string
    bcdTime_t time;
    if(RTCC_TimeGet(&time) == true){
        sprintf(date, "%02d/%02d/20%02d   %02d:%02d", time.tm_mday, time.tm_mon, time.tm_year, time.tm_hour, time.tm_min);
    }
    
    menu_main.outOfDate = true;
}

//Returns a pointer to the selected menu float or NULL if there is none
static MenuFloat_t* GetSelectedMenuFloat(void){
    
    if(selectedChannel == 1 || selectedChannel == 2){
        if(isVoltageSelected)
            return &_GLOBAL_VAR_CH(selectedChannel).setVoltage;
        else
            return &_GLOBAL_VAR_CH(selectedChannel).setCurrent;
    }

    return NULL;
}
